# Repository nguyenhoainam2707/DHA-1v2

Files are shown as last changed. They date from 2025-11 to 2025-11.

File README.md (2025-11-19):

# 🌟 DHA-1 Industrial IoT Data Acquisition System

<div align="center">






**Professional Industrial IoT Data Acquisition System**  
*Powered by ESP32-S3 with Web-based Configuration Portal*

</div>

---

## 📋 Mục Lục

- [🔍 Giới Thiệu](#-giới-thiệu)
- [✨ Tính Năng Chính](#-tính-năng-chính)
- [🏗️ Cấu Trúc Dự Án](#️-cấu-trúc-dự-án)
- [🛠️ Cài Đặt và Build](#️-cài-đặt-và-build)
- [🌐 Web Configuration Portal](#-web-configuration-portal)
- [📡 API Documentation](#-api-documentation)
- [🔧 Hardware Requirements](#-hardware-requirements)
- [📊 Protocols Supported](#-protocols-supported)
- [🚀 Quick Start](#-quick-start)
- [📖 Hướng Dẫn Sử Dụng](#-hướng-dẫn-sử-dụng)
- [🤝 Contributing](#-contributing)

---

## 🔍 Giới Thiệu

**DHA-1** là hệ thống thu thập dữ liệu công nghiệp IoT chuyên nghiệp được xây dựng trên nền tảng **ESP32-S3**. Hệ thống cung cấp giao diện web hiện đại để cấu hình và giám sát đến **10 sensor** với nhiều giao thức khác nhau, bao gồm **ADC 4-20mA** và **RS485 Modbus**, đồng thời cung cấp cho người dùng các cảnh báo, để điều khiển các relay hoặc đọc trạng thái của cảm biến thông qua các input đầu vào. 

### 🎯 Mục Tiêu

- **Đơn giản hóa** việc cấu hình hệ thống công nghiệp
- **Chuẩn hóa** giao diện web cho các thiết bị IoT
- **Tối ưu hóa** hiệu suất và độ tin cậy
- **Mở rộng** khả năng tích hợp với các hệ thống SCADA/MES

---

## ✨ Tính Năng Chính

### 🌐 **Web Configuration Portal**
- ✅ Giao diện web responsive hiện đại
- ✅ Dashboard real-time với cập nhật tự động 
- ✅ Cấu hình sensor với Point Table Calibration
- ✅ Cấu hình truyền file FTP theo thông tư 10 và 17 BTNMT
- ✅ Authentication với mật khẩu và password
- ✅ Export/Import cấu hình dạng JSON

### 📊 **Multi-Protocol Sensor Support**
- ✅ **ADC 4-20mA**: 4 cổng dọc tín hiệu analog chuẩn công nghiệp
- ✅ **RS485 Modbus RTU**: 2 channels, mỗi channel tối đa 10 slaves
- ✅ **Digital Input**: 4 channels
- ✅ **Digital Output**: 4 channels

### 🔧 **Advanced Features**
- ✅ **Real-time Clock (RTC)**: DS3231 với battery backup
- ✅ **LCD Display**: 16x2 I2C với backlight control
- ✅ **SD Card Logging**: Automatic data logging
- ✅ **MQTT Integration**: Publish/Subscribe capabilities
- ✅ **FTP Server**: Remote file management

### 📱 **User Experience**
- ✅ **Tabbed Interface**: Organized configuration sections
- ✅ **Live Data Updates**: 2-second refresh rate
- ✅ **Mobile Responsive**: Works on phones and tablets
- ✅ **Error Handling**: Comprehensive error action
- ✅ **Auto-restart**: Configuration changes trigger restart

---

## 🏗️ Cấu Trúc Dự Án

```
DHA-1/
├── 📁 src/
│   ├── 📄 main.cpp                    # Entry point
│   ├── 📁 apps/                       # Application modules
│   │   ├── 📄 App.h                   # Base application class
│   │   ├── 📄 atApp_AP.h              # Access Point & Web Server
│   │   ├── 📄 atApp_Sensor.h          # Sensor management
│   │   ├── 📄 atApp_MQTT_PUB.h        # MQTT Publisher
│   │   ├── 📄 atApp_RTC_v2.h          # Real-time Clock
│   │   ├── 📄 atApp_LCD.h             # LCD Display
│   │   ├── 📄 webApp.h                # Web interface (auto-generated)
│   │   └── 📄 ...                     # Other application modules
│   ├── 📁 obj/                        # Data objects
│   │   ├── 📄 Object.h                # Base object class
│   │   ├── 📄 atObj_Data.h            # Runtime data structure
│   │   └── 📄 atObj_Param.h           # Configuration parameters
│   └── 📁 services/                   # Hardware abstraction
│       ├── 📄 Service.h               # Base service class
│       ├── 📄 atService_ADS1115.h     # ADC service
│       ├── 📄 atService_Modbus.h      # Modbus RTU
│       ├── 📄 atService_DS3231.h      # RTC service
│       └── 📄 ...                     # Other hardware services
├── 📁 data/                           # Web assets
│   ├── 📄 webApp.html                 # Main web interface
│   └── 📄 sensor.html                 # Sensor calibration table
├── 📁 lib/                            # External libraries (ZIP format)
│   ├── 📦 ArduinoJson.zip
│   ├── 📦 RTClib.zip
│   ├── 📦 ModbusMaster.zip
│   └── 📦 ...
├── 📄 platformio.ini                  # PlatformIO configuration
├── 📄 embed_html.py                   # Build script (HTML embedding)
└── 📄 README.md                       # This file
```

---

## 🛠️ Cài Đặt và Build

### 📋 Prerequisites

- **PlatformIO IDE** hoặc **PlatformIO Core**
- **ESP32-S3** DHA-1v1
- **USB-B cable** cho lập trình

### 🚀 Build Instructions

1. **Clone repository:**
```bash
git clone https://github.com/MINHDUONGJSC/DHA-1.git
cd DHA-1
```

2. **Install dependencies:**
```bash
pio lib install
```

3. **Build firmware:**
```bash
pio run
```

4. **Upload to ESP32-S3:**
```bash
pio run --target upload
```

5. **Monitor serial output:**
```bash
pio device monitor
```

### ⚙️ Configuration Files

| File | Purpose | Format |
|---|---|---|
| `platformio.ini` | Build configuration | INI |
| `embed_html.py` | HTML embedding script | Python |

---

## 🌐 Web Configuration Portal

### 🔐 Access Information

- **SSID**: `DHA-1`
- **Password**: `12345678`
- **IP Address**: `192.168.4.1`
- **Login**: `admin` / `admin123`

### 📱 Interface Features

#### 🏠 **Dashboard Tab**
- **Real-time sensor readings** (update every 2 seconds)
- **System status indicators**
- **Alarm and warning displays**
- **Uptime and memory usage**

#### ⚙️ **Configuration Tabs**

| Tab | Description | Features |
|-----|---|---|
| **General** | System settings | Device name, time zone, network |
| **Sensors** | Sensor configuration | Protocol, calibration, limits |
| **Digital I/O** | I/O configuration | Input/output mapping, control logic |
| **RS485** | Modbus settings | 2 channels, 10 slaves per channel |
| **MQTT** | MQTT integration | Broker settings, topics |
| **RTC** | Time settings | Auto-sync, timezone |
| **LCD** | Display settings | Backlight, refresh rate |

#### 🔧 **Advanced Features**

- **Point Table Calibration**: 10-point linearization
- **Error Thresholds**: Configurable alarm levels
- **Data Export**: Download configuration as JSON
- **Firmware Update**: OTA capability
- **Log Viewer**: Real-time log display

---

## 📡 API Documentation

### 🔑 Authentication

All API calls require JWT authentication header:
```http
Authorization: Bearer <token>
```

### 🌐 Endpoints

#### **Authentication**
```http
POST /api/login
Content-Type: application/json

{
  "username": "admin",
  "password": "admin123"
}
```

#### **Configuration**
```http
GET /api/config          # Get full configuration
POST /api/save           # Save configuration
GET /api/dashboard       # Get real-time data
GET /api/rtc            # Get RTC information
```

#### **Response Format**
```json
{
  "success": true,
  "data": {
    "sensors": [
      {
        "id": 0,
        "name": "Temperature",
        "raw": 2048.5,
        "calib": 25.3,
        "status": 0,
        "unit": "°C"
      }
    ],
    "system": {
      "uptime": 3600,
      "free_heap": 245760,
      "rtc_temp": 24.5
    }
  }
}
```

---

## 🔧 Hardware Requirements

### 💾 **ESP32-S3 Specifications**

| Component | Requirement | Notes |
|---|---|---|
| **MCU** | ESP32-S3 | Dual-core, 240MHz |
| **Flash** | 16MB | For firmware + web assets |
| **PSRAM** | 8MB | For buffering and processing |
| **WiFi** | 802.11 b/g/n | Access Point mode |

### 🔌 **External Components**

| Component | Interface | Purpose |
|---|---|---|
| **ADS1115** | I2C | 16-bit ADC for 4-20mA |
| **DS3231** | I2C | Real-time clock |
| **LCD 16x2** | I2C | Local display |
| **SD Card** | SPI | Data logging |
| **RS485 Transceiver x2** | UART | 2-channel Modbus communication |
| **PCF8574** | I2C | I/O expansion |
| **74HC595** | SPI | Output expansion |

---

## 📊 Protocols Supported

### 🔧 **ADC 4-20mA**
- **Resolution**: 16-bit (ADS1115)
- **Range**: 4-20mA industrial standard
- **Accuracy**: ±0.1% FSR
- **Calibration**: Point table or polynomial

### 📡 **RS485 Modbus RTU**
- **Channels**: 2 independent channels
- **Slaves per Channel**: Up to 10 devices
- **Total Slaves**: Maximum 20 devices
- **Baud Rate**: 9600, 19200, 38400, 115200
- **Data Bits**: 8
- **Parity**: None, Even, Odd
- **Stop Bits**: 1, 2
- **Functions**: 03 (Read Holding), 04 (Read Input)

### 🌐 **MQTT**
- **Version**: 3.1.1
- **QoS**: 0, 1, 2
- **Topics**: Configurable publish/subscribe
- **Payload**: JSON format
- **SSL/TLS**: Supported

---

## 🚀 Quick Start

### 1️⃣ **Hardware Setup**
```
1. Connect ESP32-S3 to power
2. Wire I2C devices (SDA=21, SCL=22)
3. Connect RS485 transceiver
4. Insert SD card
5. Power on system
```

### 2️⃣ **Network Connection**
```
1. Connect to WiFi "DHA-1"
2. Password: "12345678"
3. Open browser: http://192.168.4.1
4. Login: admin / admin123
```

### 3️⃣ **Sensor Configuration**
```
1. Go to "Sensors" tab
2. Enable desired sensors
3. Select protocol (ADC/RS485)
4. Configure calibration
5. Set alarm thresholds
6. Save configuration
```

### 4️⃣ **Monitoring**
```
1. Switch to "Dashboard" tab
2. View real-time data
3. Monitor system status
4. Check alarm conditions
```

---

## 📖 Hướng Dẫn Sử Dụng

### 🔧 **Cấu Hình Sensor**

#### **ADC 4-20mA Setup:**
1. Chọn **Protocol**: ADC
2. Cấu hình **Calibration**:
   - Linear: `y = A + Bx`
   - Point Table: Nhập 10 điểm chuẩn
3. Thiết lập **Error Thresholds**
4. Cấu hình **Output Limits**

#### **RS485 Modbus Setup:**
1. Chọn **Protocol**: RS485
2. Chọn **Channel** (1 hoặc 2)
3. Chọn **Slave Device** (1-10 per channel)
4. Cấu hình **Register Address**
5. Thiết lập **Data Type** (INT16, FLOAT, etc.)
6. Áp dụng **Calibration Function**

### 📊 **Dashboard Usage**

- **Sensor Cards**: Hiển thị real-time data
- **Status Colors**:
  - 🟢 **Green**: Normal operation
  - 🟡 **Orange**: Calibration mode
  - 🔴 **Red**: Error condition
- **Auto-refresh**: Cập nhật mỗi 2 giây

### 💾 **Data Management**

- **Save Config**: Lưu cấu hình vào SD card
- **Export**: Download file JSON
- **Backup**: Tự động backup định kỳ
- **Restore**: Import từ file JSON

---

## 🤝 Contributing

### 📋 **Development Guidelines**

1. **Fork** repository
2. **Create** feature branch
3. **Follow** coding standards
4. **Test** thoroughly
5. **Submit** pull request

### 🐛 **Bug Reports**

Sử dụng GitHub Issues với template:
- **Environment**: Hardware, firmware version
- **Steps**: Cách tái hiện lỗi
- **Expected**: Kết quả mong đợi
- **Actual**: Kết quả thực tế

### 💡 **Feature Requests**

- Mô tả chi tiết tính năng
- Giải thích use case
- Đề xuất implementation

---

## 📞 Contact & Support

<div align="center">

**🏢 MASSOFT**  
*Industrial IoT & Automation Solutions*

📧 **Email**: support@massoft.vn  
🌐 **Website**: https://massoft.vn  
📱 **Phone**: +84 XXX XXX XXX

---

**© 2025 MASSOFT. All rights reserved.**

</div>

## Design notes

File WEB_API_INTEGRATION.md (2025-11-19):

# Web API Integration Guide

## Đã hoàn thành trong atApp_AP.h

### 1. Access Point Configuration
- **SSID**: `DHA-1_Config`
- **Password**: `12345678`
- **IP Address**: `192.168.4.1`
- **Max Connections**: 4 clients

### 2. API Endpoints

#### Authentication
- **POST** `/api/login`
  - Body: `{"username":"admin", "password":"admin123"}`
  - Response: `{"success":true, "token":"xxxxx"}`

- **POST** `/api/logout`
  - Response: `{"success":true, "message":"Logged out"}`

#### Configuration
- **GET** `/api/config` (requires auth)
  - Returns full configuration from atObj_Param

- **POST** `/api/save` (requires auth)
  - Body: Full configuration JSON
  - Saves to SD card and restarts ESP32

#### Dashboard
- **GET** `/api/dashboard` (requires auth)
  - Returns real-time sensor data from atObj_Data

### 3. Cần cập nhật trong webApp.html

#### Function: handleLogin()
```javascript
function handleLogin(event) {
    event.preventDefault();
    
    const username = document.getElementById('loginUsername').value;
    const password = document.getElementById('loginPassword').value;
    
    fetch('http://192.168.4.1/api/login', {
        method: 'POST',
        headers: { 'Content-Type': 'application/json' },
        body: JSON.stringify({ username, password })
    })
    .then(response => response.json())
    .then(data => {
        if (data.success) {
            localStorage.setItem('authToken', data.token);
            hideLogin();
            loadConfiguration(); // Load config after login
        } else {
            document.getElementById('loginError').style.display = 'block';
        }
    })
    .catch(error => console.error('Login error:', error));
}
```

#### Function: loadConfiguration()
```javascript
function loadConfiguration() {
    fetch('http://192.168.4.1/api/config', {
        method: 'GET',
        headers: { 'Authorization': 'Bearer ' + localStorage.getItem('authToken') }
    })
    .then(response => response.json())
    .then(data => {
        // Populate form fields with data
        if (data.device_info) {
            document.getElementById('deviceName').value = data.device_info.device_name;
            document.getElementById('deviceId').value = data.device_info.device_id;
            // ... populate other fields
        }
        
        if (data.sensors) {
            data.sensors.forEach((sensor, index) => {
                // Populate sensor configuration
            });
        }
        
        // ... populate MQTT, RTC, etc.
    })
    .catch(error => console.error('Load config error:', error));
}
```

#### Function: saveConfig()
```javascript
function saveConfig() {
    // Collect all form data
    const config = {
        device_info: {
            device_name: document.getElementById('deviceName').value,
            device_id: document.getElementById('deviceId').value,
            // ... collect other fields
        },
        lcd_config: {
            enable: document.getElementById('lcdEnable').checked,
            backlight_enable: document.getElementById('lcdBacklight').checked,
            refresh_rate: parseInt(document.getElementById('lcdRefreshRate').value)
        },
        sensors: [],
        mqtt: {},
        rtc: {}
        // ... collect all configurations
    };
    
    fetch('http://192.168.4.1/api/save', {
        method: 'POST',
        headers: { 
            'Content-Type': 'application/json',
            'Authorization': 'Bearer ' + localStorage.getItem('authToken')
        },
        body: JSON.stringify(config)
    })
    .then(response => response.json())
    .then(data => {
        if (data.success) {
            showMessage('Configuration saved! Device restarting...', 'success');
        } else {
            showMessage('Failed to save: ' + data.message, 'error');
        }
    })
    .catch(error => {
        console.error('Save error:', error);
        showMessage('Network error: ' + error, 'error');
    });
}
```

#### Function: updateDashboard()
```javascript
function updateDashboard() {
    fetch('http://192.168.4.1/api/dashboard', {
        method: 'GET',
        headers: { 'Authorization': 'Bearer ' + localStorage.getItem('authToken') }
    })
    .then(response => response.json())
    .then(data => {
        if (data.sensors) {
            data.sensors.forEach(sensor => {
                // Update dashboard display
                document.getElementById('sensor' + sensor.id + 'Raw').value = sensor.raw.toFixed(2);
                document.getElementById('sensor' + sensor.id + 'Calib').value = sensor.calib.toFixed(2);
                document.getElementById('sensor' + sensor.id + 'Status').textContent = getStatusText(sensor.status);
            });
        }
        
        // Update system info
        document.getElementById('uptime').textContent = formatUptime(data.uptime);
        document.getElementById('freeHeap').textContent = formatBytes(data.free_heap);
        document.getElementById('clients').textContent = data.clients;
    })
    .catch(error => console.error('Dashboard update error:', error));
}

// Auto-refresh dashboard every 2 seconds
setInterval(updateDashboard, 2000);
```

### 4. Security Notes

⚠️ **Important**: Current implementation uses simple authentication
- Username: `admin`
- Password: `admin123`
- Session timeout: 1 hour

**Khuyến nghị cho production:**
1. Thay đổi mật khẩu mặc định
2. Sử dụng HTTPS (ESP32 hỗ trợ)
3. Implement proper JWT tokens
4. Hash passwords với bcrypt
5. Add CSRF protection

### 5. Memory Management

Code đã được tối ưu hóa để tránh tràn RAM:
- Sử dụng `JsonDocument` với auto memory management (ArduinoJson v7)
- Gửi JSON theo chunks nhỏ thay vì full config
- Clear JSON document sau khi sử dụng: `doc.clear()`
- Delay 500ms trước khi restart để đảm bảo response được gửi

### 6. Testing Checklist

- [ ] Kết nối WiFi AP "DHA-1_Config"
- [ ] Truy cập http://192.168.4.1
- [ ] Login với admin/admin123
- [ ] Load configuration từ SD card
- [ ] Chỉnh sửa các thông số
- [ ] Save configuration
- [ ] Kiểm tra file Config.json trên SD card
- [ ] Verify ESP32 restart sau khi save
- [ ] Dashboard hiển thị real-time data

### 7. Troubleshooting

**Lỗi "Unauthorized":**
- Kiểm tra localStorage có authToken không
- Session có thể đã timeout (1 giờ)
- Login lại

**Lỗi "SD card not available":**
- Kiểm tra SD card được khởi tạo chưa
- Gọi `atService_SD.begin()` trong main code

**RAM overflow:**
- Giảm số sensors hiển thị trên dashboard
- Tăng delay giữa các request
- Monitor free heap: `ESP.getFreeHeap()`

**Web không load:**
- Kiểm tra đã include file `webApp.h`
- File HTML quá lớn → nén hoặc chia nhỏ
- Tăng stack size của task: `xTaskCreate(..., 8192, ...)`

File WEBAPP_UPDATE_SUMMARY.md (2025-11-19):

# WebApp.html JavaScript Integration - Hoàn Tất

## Tóm Tắt Thay Đổi

Đã cập nhật hoàn tất các hàm JavaScript trong `webApp.html` để kết nối với ESP32 REST API.

---

## 1. Hàm loadConfiguration()

**Mục đích:** Tải cấu hình từ ESP32 và điền vào các trường form

**Endpoint:** `GET /api/config`

**Chức năng:**
- Lấy auth token từ localStorage
- Gửi GET request với Bearer token
- Parse JSON response và điền vào tất cả các trường:
  - Device Info (name, id, firmware version)
  - LCD Config (enable, backlight, refresh rate)
  - AI Config (refresh rate, 4 channels)
  - DO Config (refresh rate, 4 channels)
  - DI Config (refresh rate, 4 channels)
  - Sensor Config (10 sensors với đầy đủ thông số)
  - MQTT Config (host, port, credentials, topics)
  - RTC Config (enable flag)

**Error Handling:**
- 401 Unauthorized → logout và hiển thị login modal
- Network errors → hiển thị thông báo lỗi

**Được gọi:** Sau khi login thành công

---

## 2. Hàm saveConfig()

**Mục đích:** Lưu cấu hình xuống SD card và restart ESP32

**Endpoint:** `POST /api/save`

**Chức năng:**
- Thu thập tất cả dữ liệu từ form fields
- Build JSON object với cấu trúc hoàn chỉnh
- Gửi POST request với Bearer token
- Hiển thị thông báo "Device restarting..."
- Clear auth token sau 3 giây (do ESP32 restart)
- Redirect về login page

**Quy trình:**
1. Confirm dialog → OK?
2. Collect form data
3. POST to /api/save
4. ESP32 updates atObj_Param
5. ESP32 calls saveConfigToJSON()
6. ESP32 delays 500ms
7. ESP32 calls ESP.restart()
8. WebApp shows countdown and logout

**Error Handling:**
- 401 Unauthorized → logout
- Network/Server errors → hiển thị lỗi

---

## 3. Hàm updateDashboard()

**Mục đích:** Cập nhật real-time data lên dashboard

**Endpoint:** `GET /api/dashboard`

**Chức năng:**
- Lấy auth token (skip nếu chưa login)
- Gửi GET request với Bearer token
- Parse JSON và cập nhật readonly fields:
  - sensor_raw_value_list[0-9] → sensor-raw-1 to sensor-raw-10
  - sensor_calib_value_list[0-9] → sensor-calib-1 to sensor-calib-10
  - sensor_status_list[0-9] → sensor-status-1 to sensor-status-10
    * 0 = Normal (green)
    * 1 = Calibration (orange)
    * 2 = Error (red)
  - ai_raw_value_list[0-3] (optional)
  - di_status_list[0-3] (optional)
  - do_status_list[0-3] (optional)

**Auto-refresh:**
- `setInterval(updateDashboard, 2000)` → cập nhật mỗi 2 giây
- Dừng khi 401 Unauthorized

**Error Handling:**
- 401 → stop refresh (không logout vì có thể đang offline)
- Network errors → log to console only

---

## 4. Helper Functions

### showSuccess(message)
- Hiển thị thông báo thành công màu xanh
- Tự động ẩn sau 5 giây

### showError(message)
- Hiển thị thông báo lỗi màu đỏ
- Tự động ẩn sau 5 giây

---

## Quy Trình Làm Việc Hoàn Chỉnh

### A. First Time Setup
```
1. Connect to WiFi "DHA-1_Config" (password: 12345678)
2. Open browser: http://192.168.4.1
3. Login page appears automatically
4. Enter username/password
5. handleLogin() sends POST /api/login
6. Receive token, save to localStorage
7. loadConfiguration() auto-called
8. Configuration populated in form
9. Dashboard starts auto-refreshing
```

### B. Modify Configuration
```
1. Edit form fields in any tab
2. Click "Save Configuration to SD Card" button
3. Confirm dialog → OK
4. saveConfig() collects all data
5. POST /api/save with complete config
6. ESP32 updates RAM variables
7. ESP32 saves to /CONFIG/Config.json
8. ESP32 delays 500ms (ensure response sent)
9. ESP32 calls ESP.restart()
10. WebApp shows "Device restarting..."
11. After 3s, logout and show login page
12. User reconnects after ~30 seconds
```

### C. Real-time Monitoring
```
1. Switch to "Dashboard" tab
2. updateDashboard() runs every 2 seconds
3. Sensor values update automatically
4. Status colors change based on state
5. No manual refresh needed
```

---

## API Endpoints Đã Tích Hợp

| Endpoint | Method | Function | Auth Required |
|---|---|---|---|
| `/api/login` | POST | handleLogin() | No |
| `/api/logout` | POST | logout() | Yes |
| `/api/config` | GET | loadConfiguration() | Yes |
| `/api/save` | POST | saveConfig() | Yes |
| `/api/dashboard` | GET | updateDashboard() | Yes |
| `/` | GET | (root page) | No |

---

## Authentication Flow

```
Login:
  → POST /api/login {username, password}
  ← {status: "success", token: "xxx"}
  → localStorage.setItem('authToken', token)
  → loadConfiguration()

API Calls:
  → Headers: {'Authorization': 'Bearer ' + token}
  
Logout:
  → POST /api/logout with token
  ← {status: "success"}
  → localStorage.removeItem('authToken')
  → showLogin()

Session Timeout:
  ← 401 Unauthorized
  → Auto logout
  → Show login page
```

---

## Memory Optimization

**ESP32 Side:**
- Use `doc.clear()` after serialization
- Send minimal dashboard JSON (only arrays)
- Chunked responses for large config
- `delay(500)` before restart

**WebApp Side:**
- Conditional dashboard updates (skip if not logged in)
- Error throttling (log only, don't spam UI)
- Clean localStorage on logout

---

## Testing Checklist

- [x] Login with correct credentials
- [x] Login with wrong credentials (should show error)
- [ ] Load configuration after login
- [ ] Verify all form fields populated correctly
- [ ] Edit configuration values
- [ ] Save configuration
- [ ] Verify "Device restarting..." message
- [ ] Verify auto-logout after save
- [ ] Reconnect after restart
- [ ] Verify changes persisted
- [ ] Dashboard auto-refresh working
- [ ] Sensor status colors correct
- [ ] Session timeout after 1 hour
- [ ] Logout button works
- [ ] Multiple tabs sync correctly

---

## Troubleshooting

### Problem: Can't login
**Solution:** Check ESP32 serial monitor for [AP] logs, verify WiFi connection

### Problem: Configuration not loading
**Solution:** Check /CONFIG/Config.json exists on SD card, verify loadConfigFromJSON() works

### Problem: Save doesn't restart device
**Solution:** Check saveConfigToJSON() returns true, verify ESP.restart() is called

### Problem: Dashboard not updating
**Solution:** Check auth token exists, verify /api/dashboard returns data, check console for errors

### Problem: 401 Unauthorized
**Solution:** Token expired (1 hour), logout and login again

---

## Code Locations

- **handleLogin()**: Line ~3392
- **logout()**: Line ~3465
- **loadConfiguration()**: Line ~3210
- **saveConfig()**: Line ~3327
- **updateDashboard()**: Line ~3820
- **showSuccess/showError()**: Line ~3503

---

## Next Steps

1. **Test trên thiết bị thật:**
   - Upload code lên ESP32-S3
   - Connect WiFi AP
   - Test toàn bộ workflow

2. **Bổ sung thêm:**
   - Password change API endpoint
   - Firmware update via web
   - Real-time logs viewer
   - Export config as JSON file
   - Import config from JSON file

3. **Tối ưu hóa:**
   - Compress JSON responses
   - WebSocket cho dashboard (thay vì polling)
   - Progressive Web App (PWA) manifest
   - Offline support

---

**Created:** $(date)
**Status:** ✅ Hoàn tất - Ready for testing
**Version:** 1.0

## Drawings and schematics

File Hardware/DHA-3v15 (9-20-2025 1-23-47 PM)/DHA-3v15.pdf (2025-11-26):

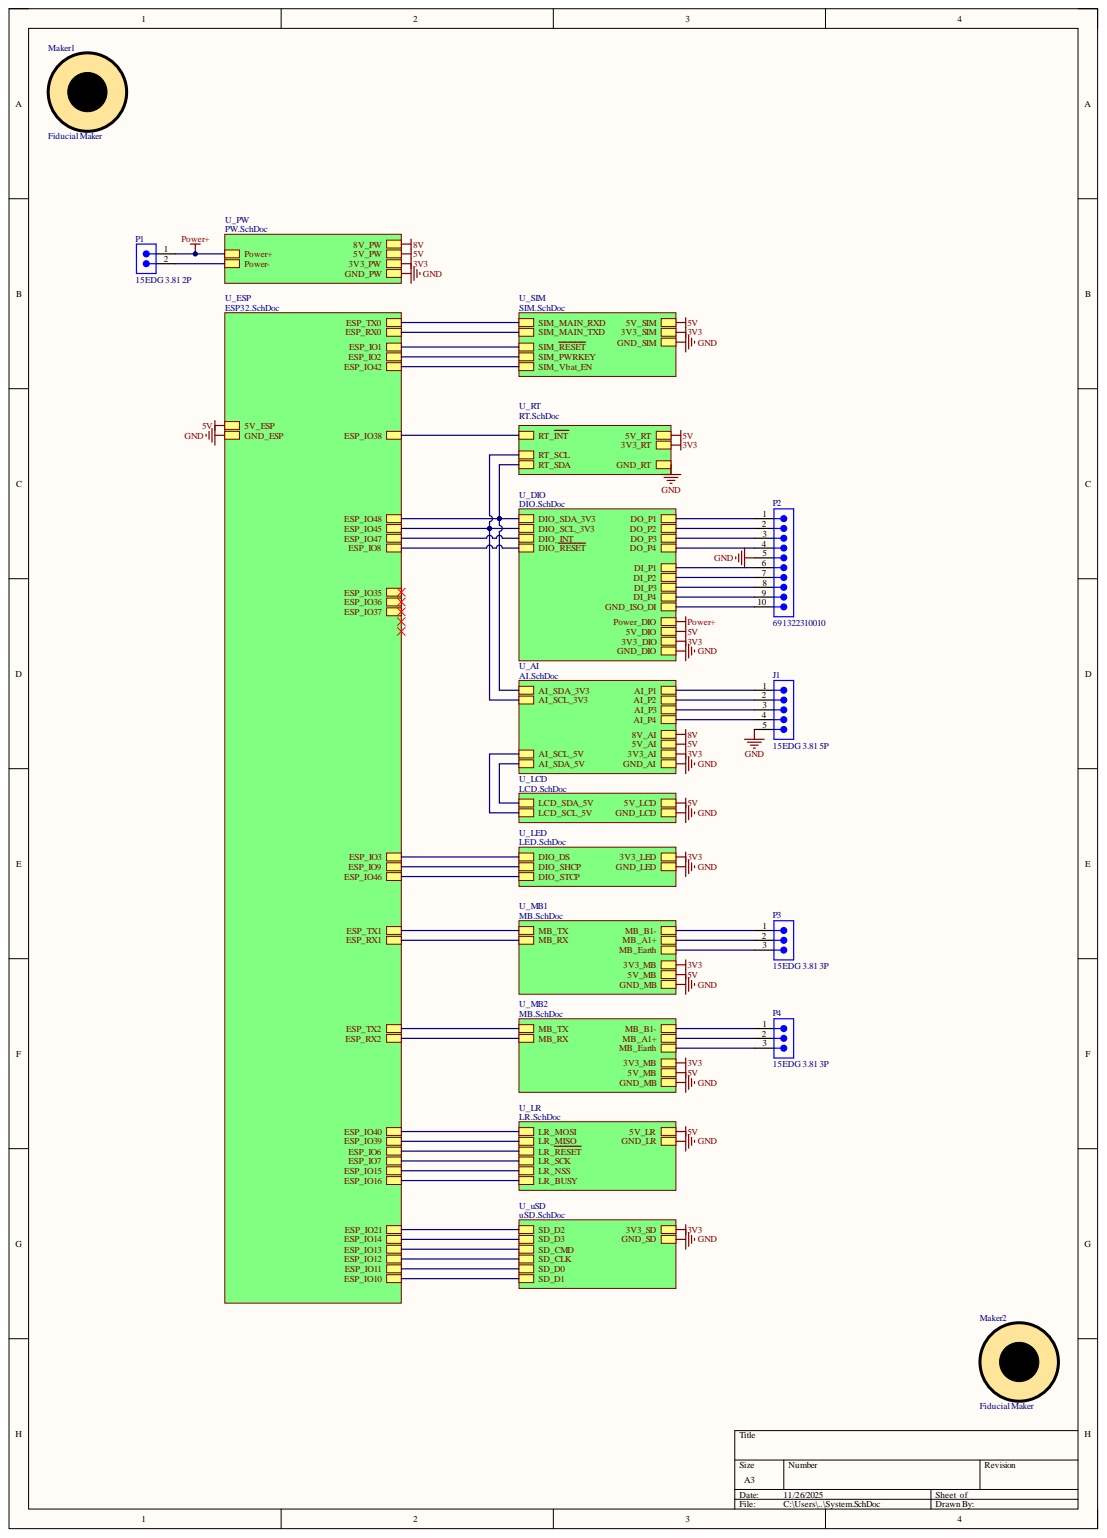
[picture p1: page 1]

Size A3 | Number | Revision

Date: 11/26/2025 | Sheet of
File: C:\Users\..\System.SchDoc | DrawnBy:

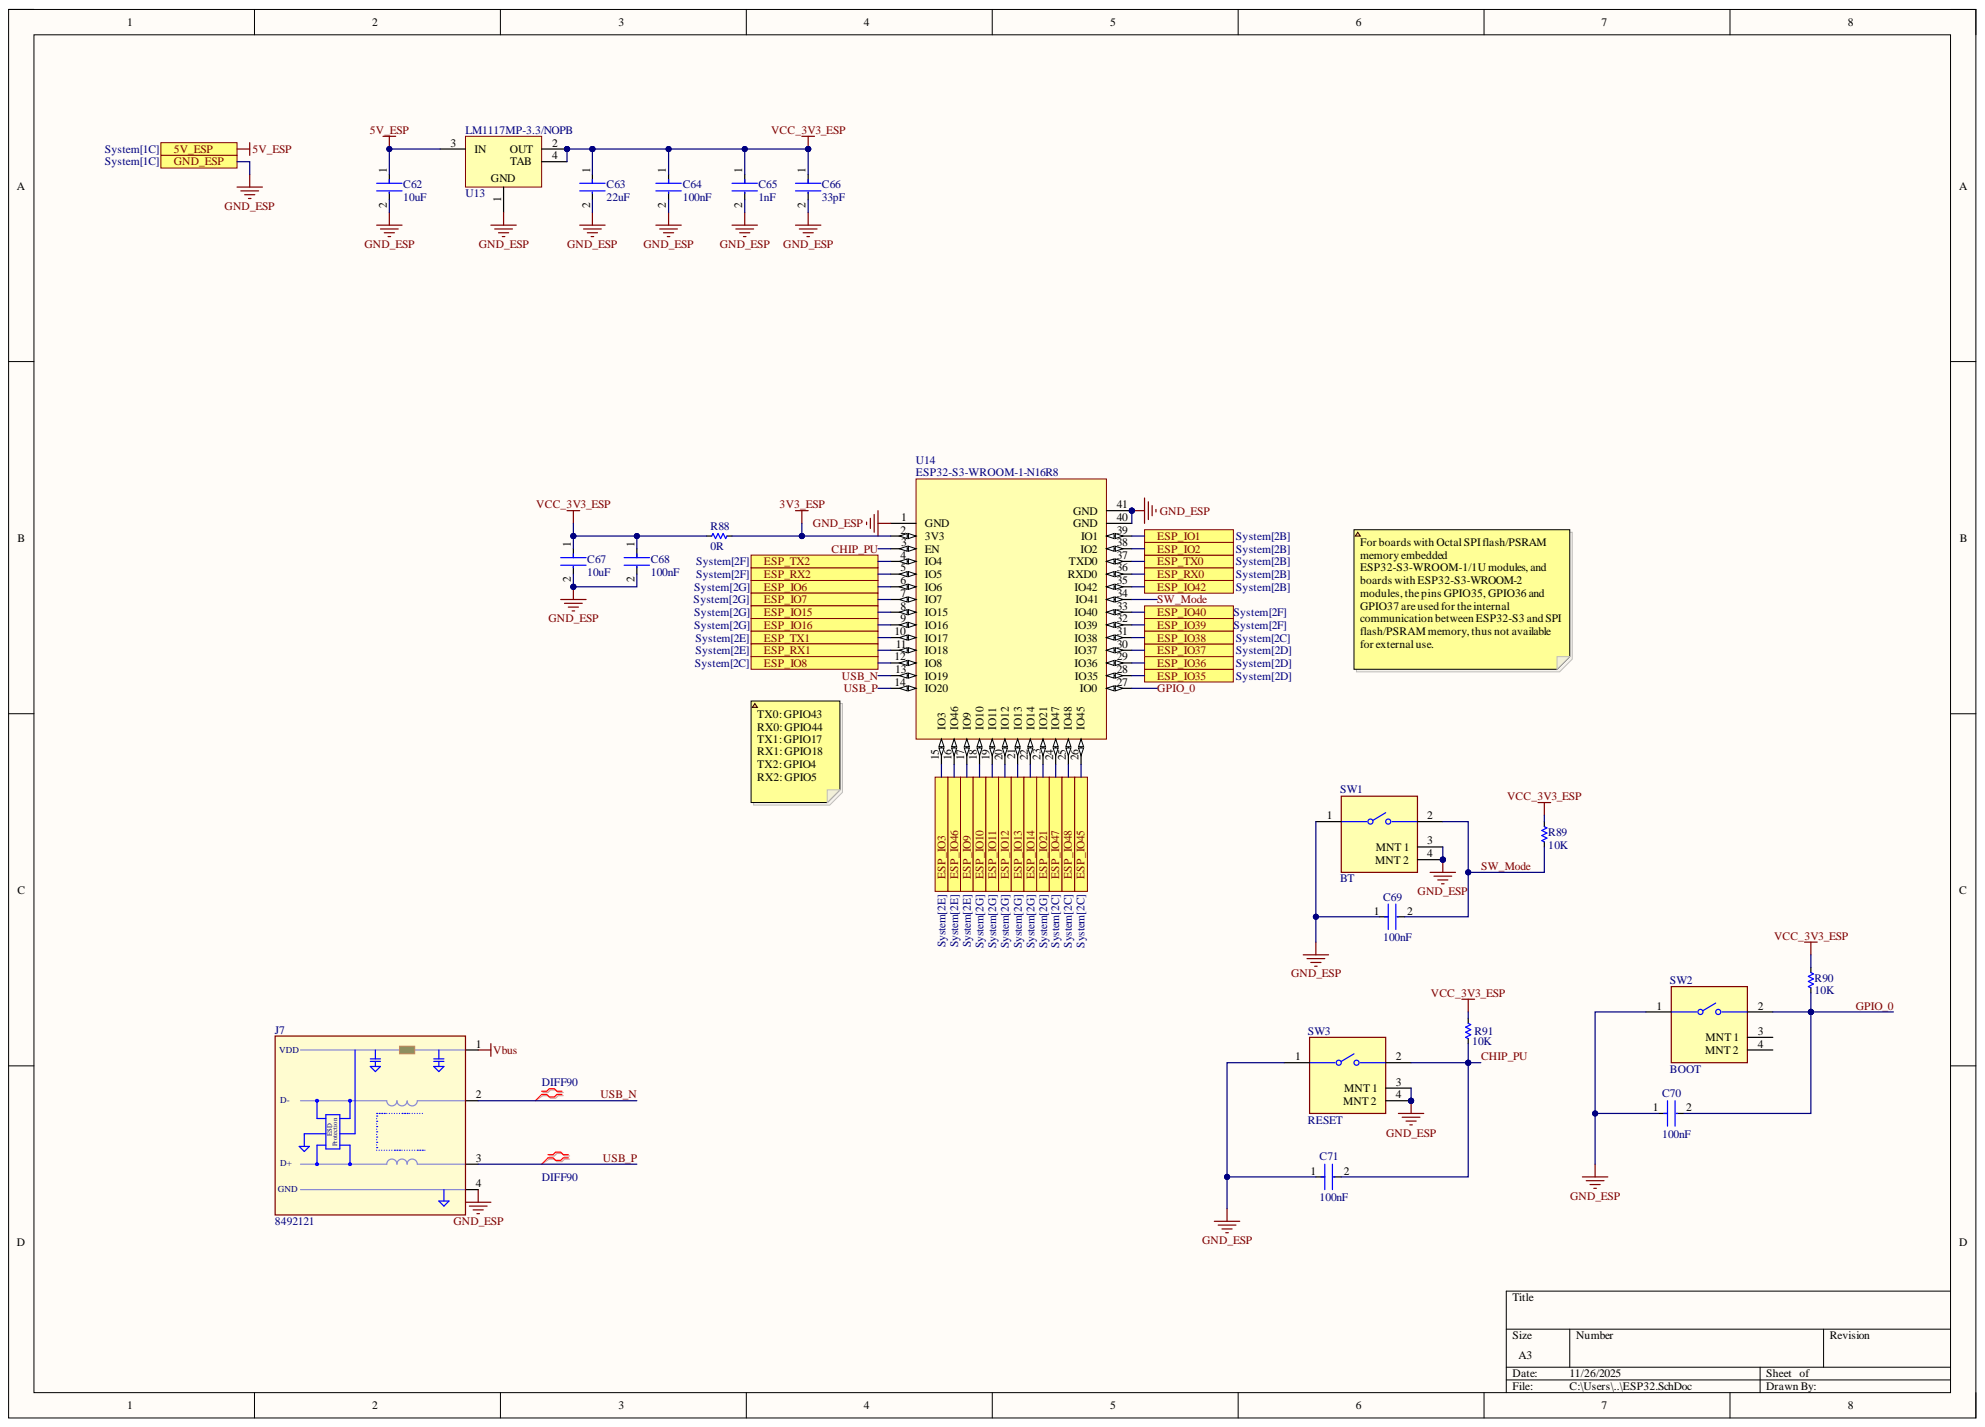
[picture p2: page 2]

For boards with Octal SPIflash/PSRAM
memory embedded
ESP32-S3-WROOM-1/1U modules, and
boards with ESP32-S3-WROOM-2
modules, the pins GPIO35, GPIO36 and
GPIO37 are used for the internal
communication between ESP32-S3 and SPI
flash/PSRAM memory, thus not available
for external use.

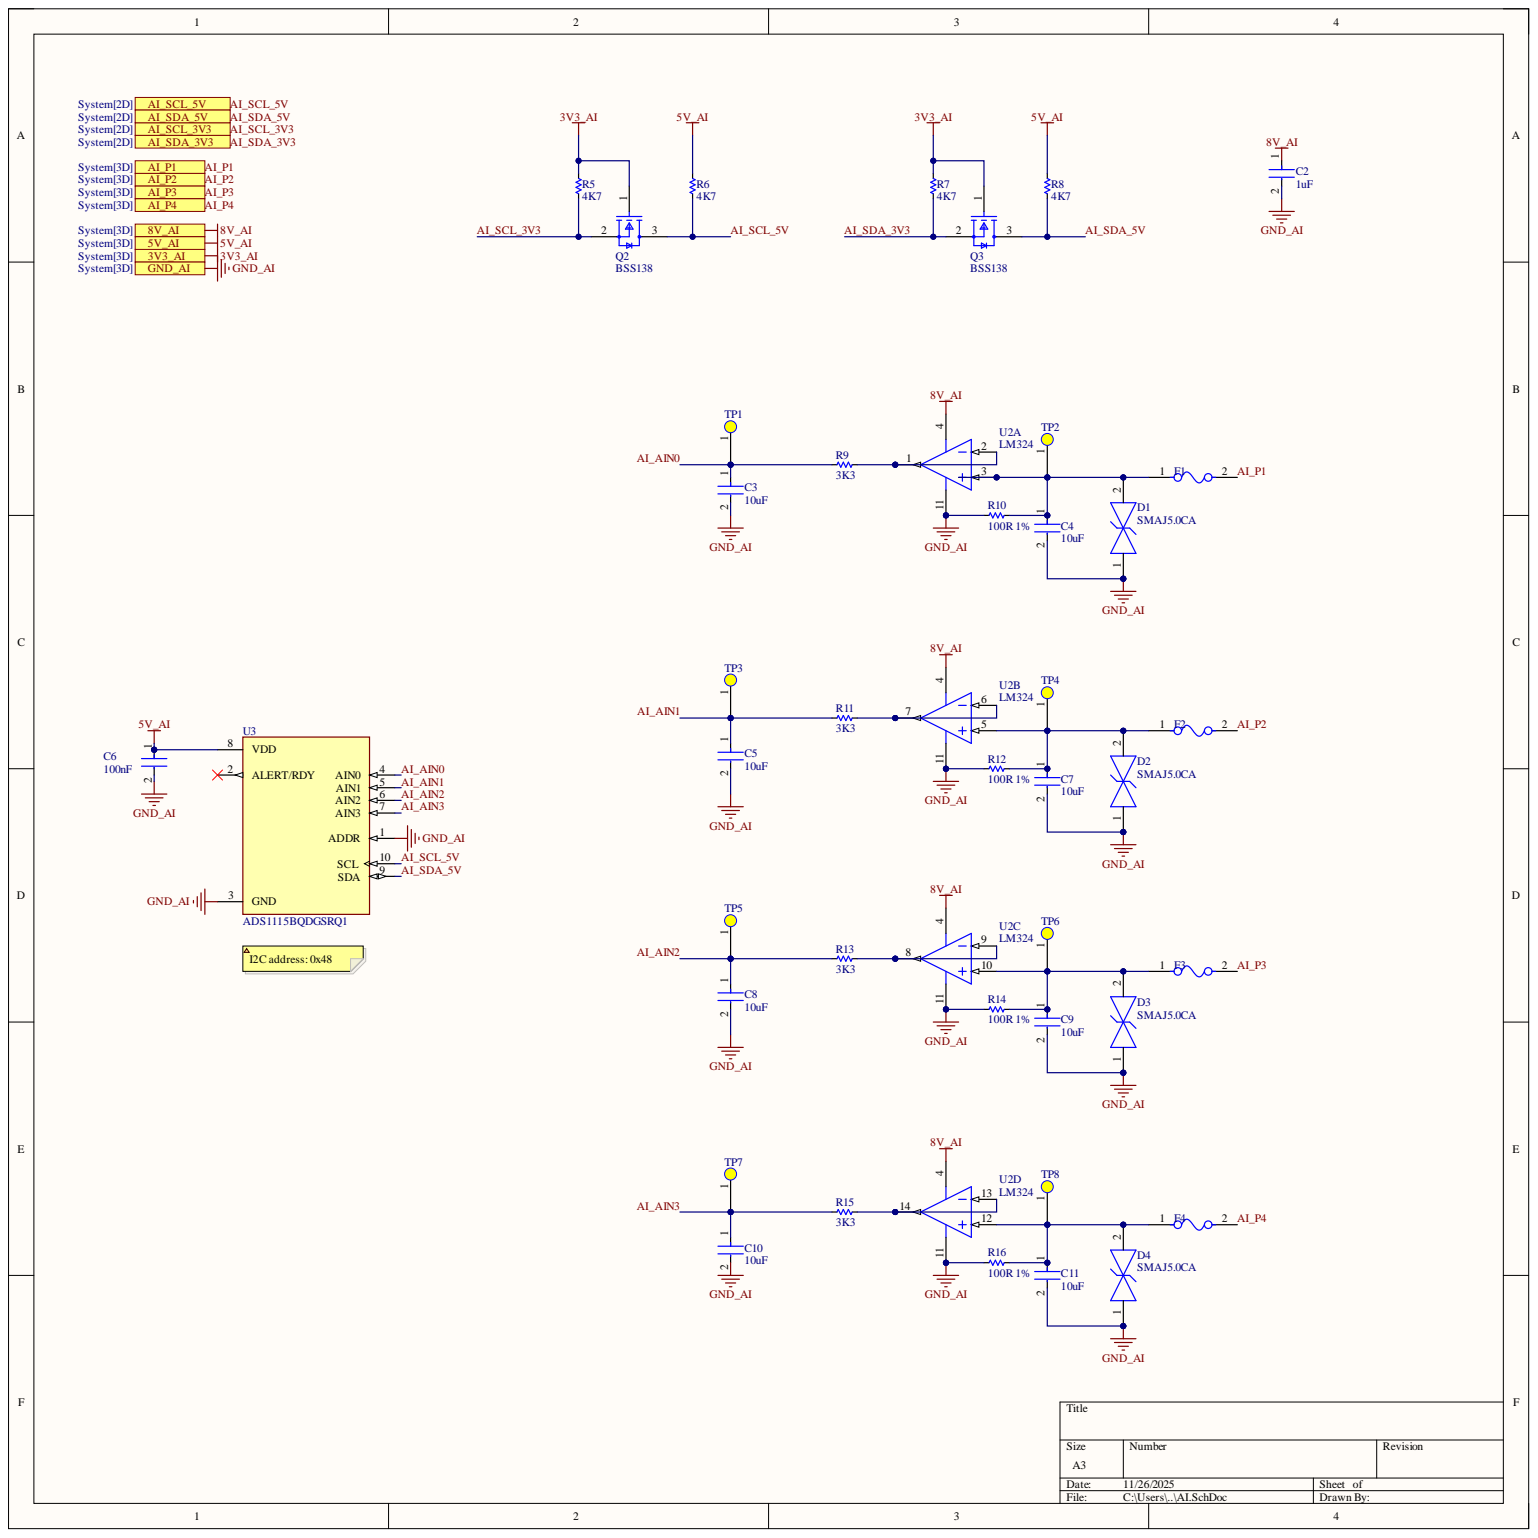
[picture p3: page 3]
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

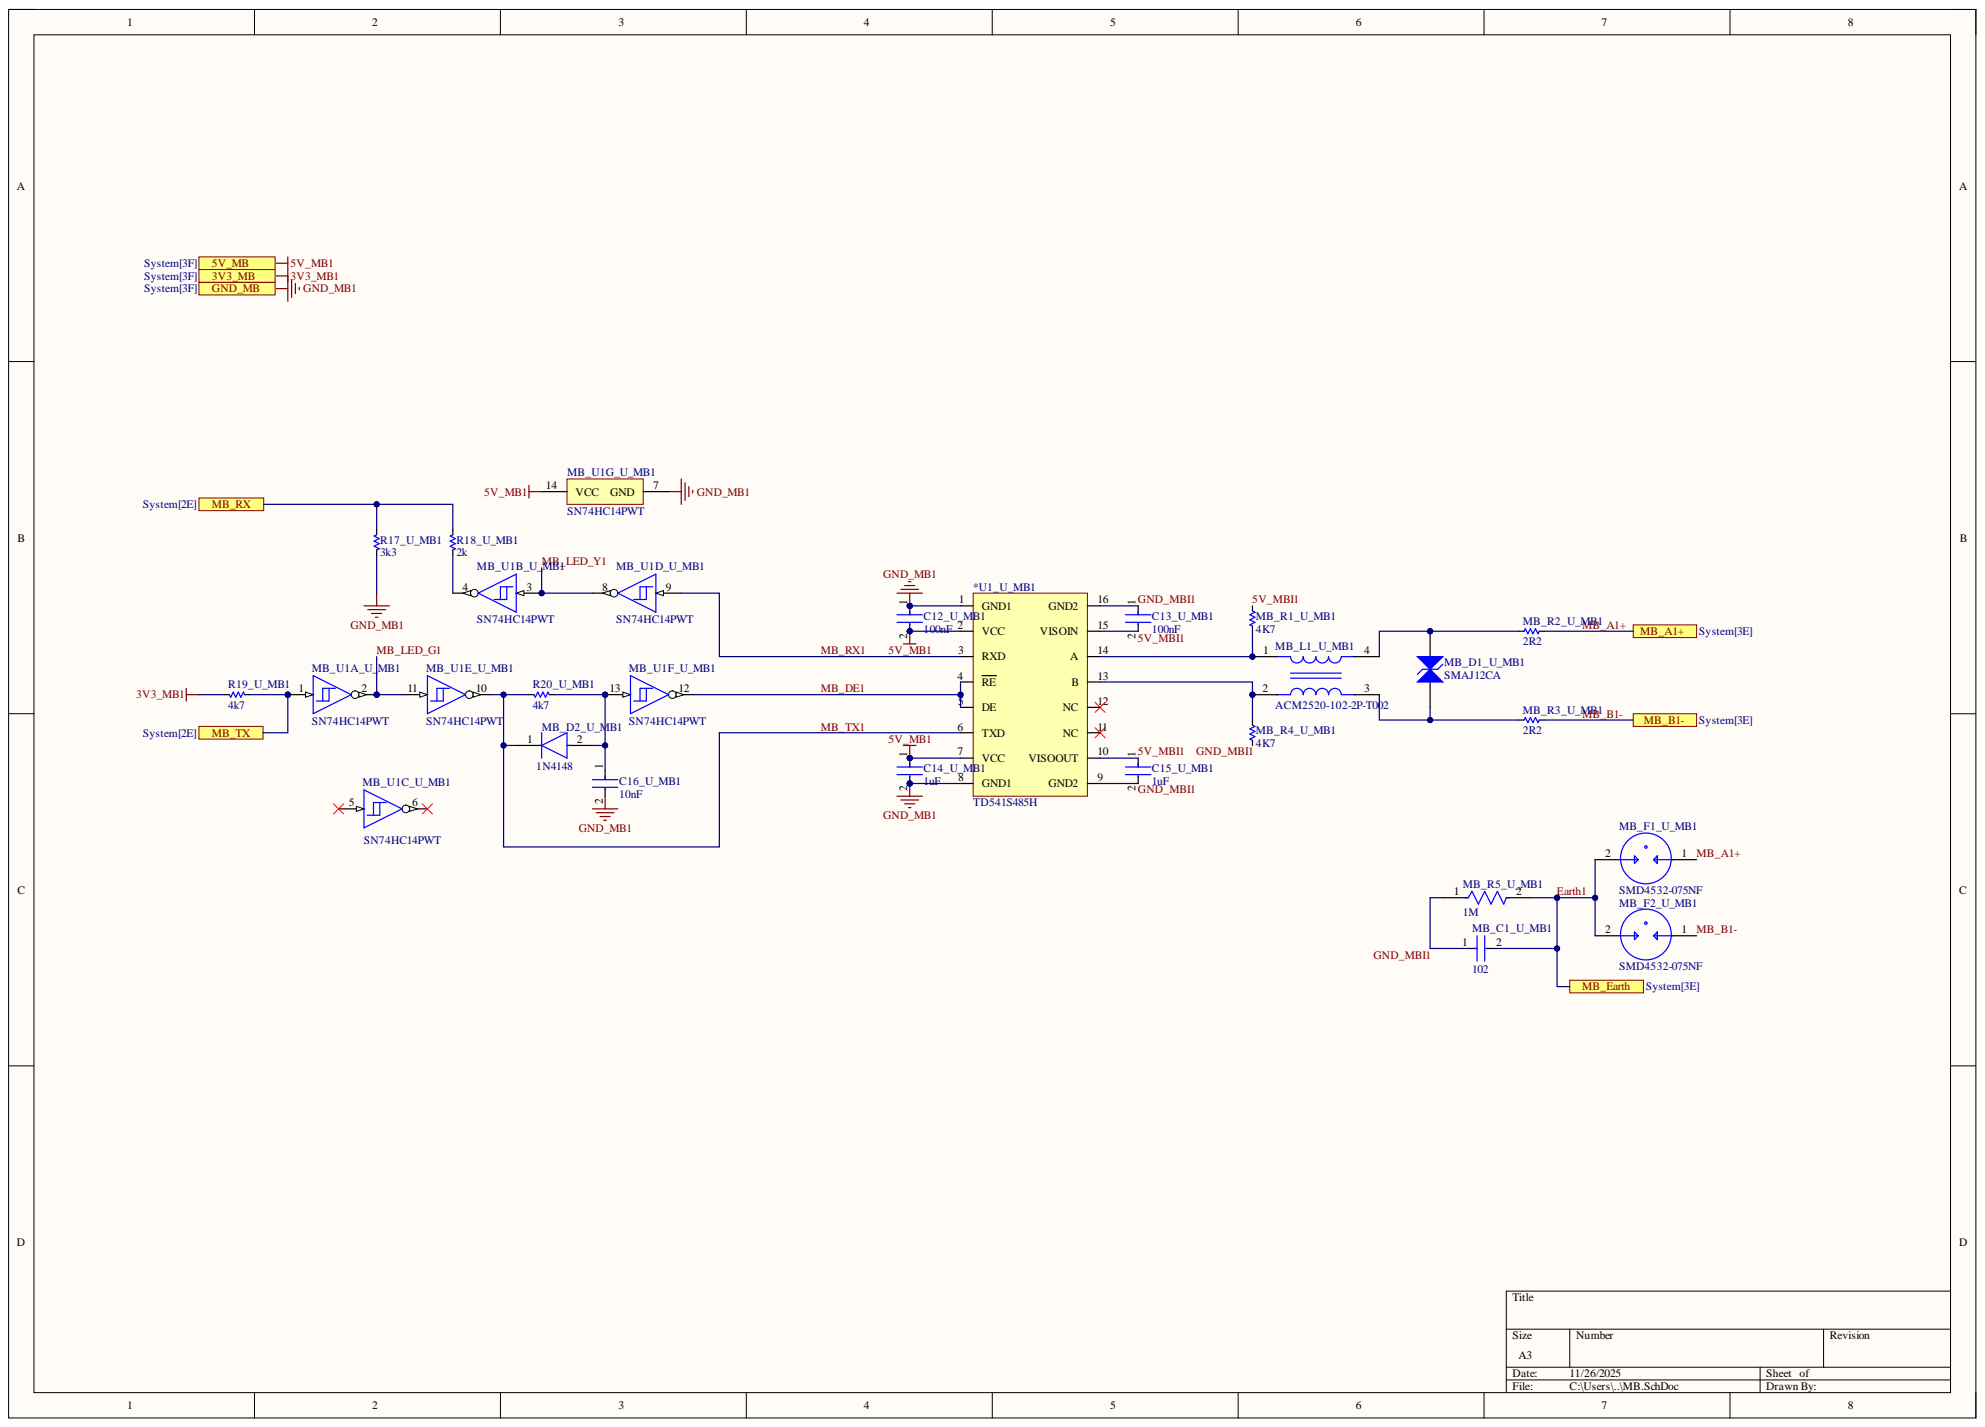
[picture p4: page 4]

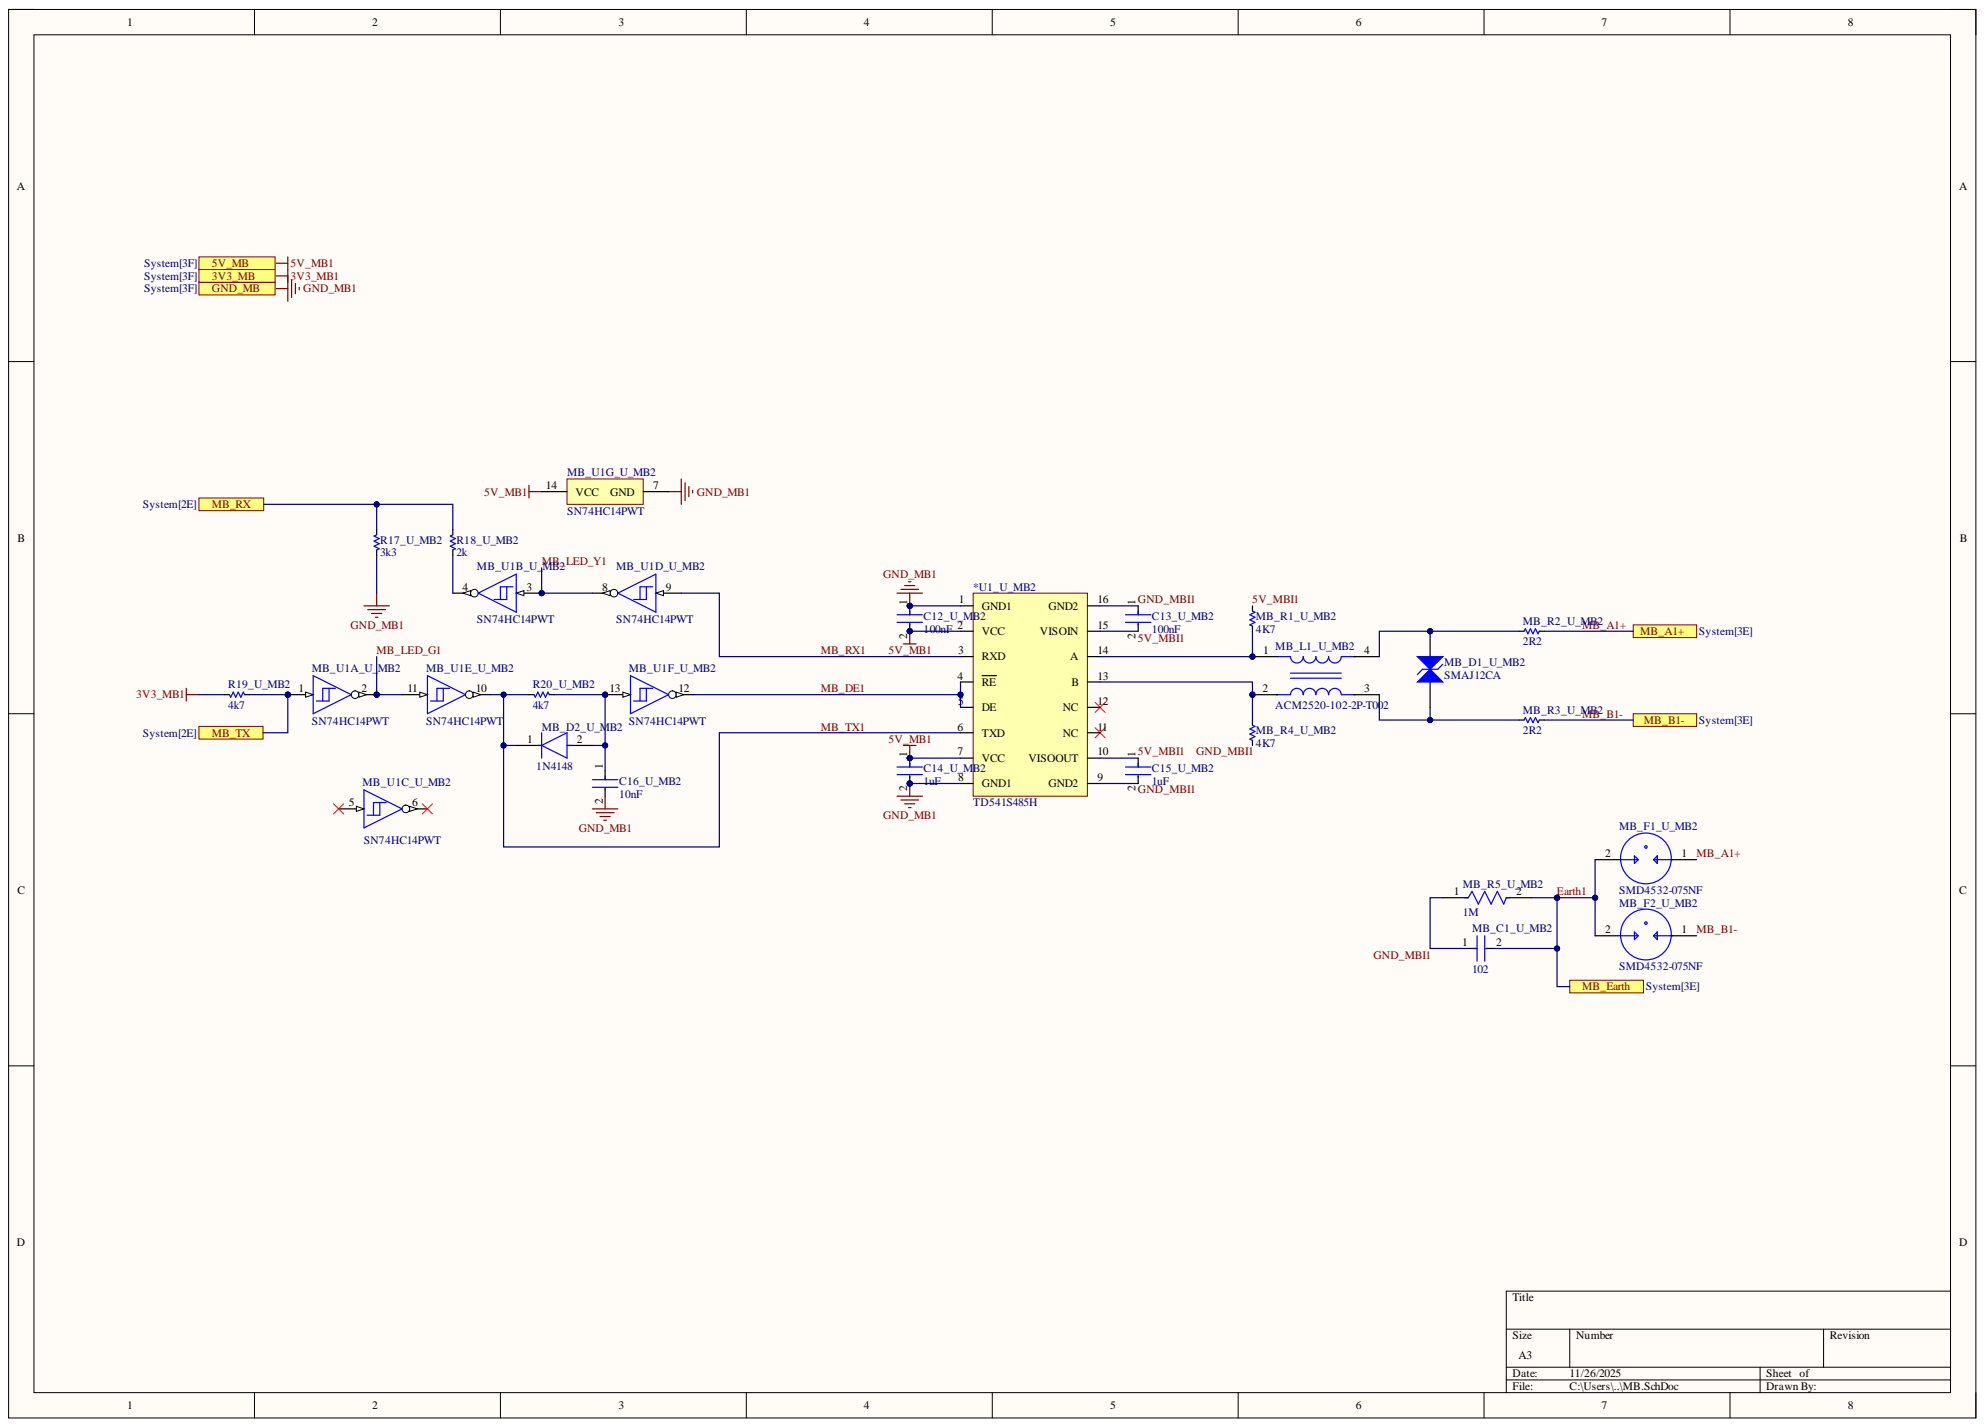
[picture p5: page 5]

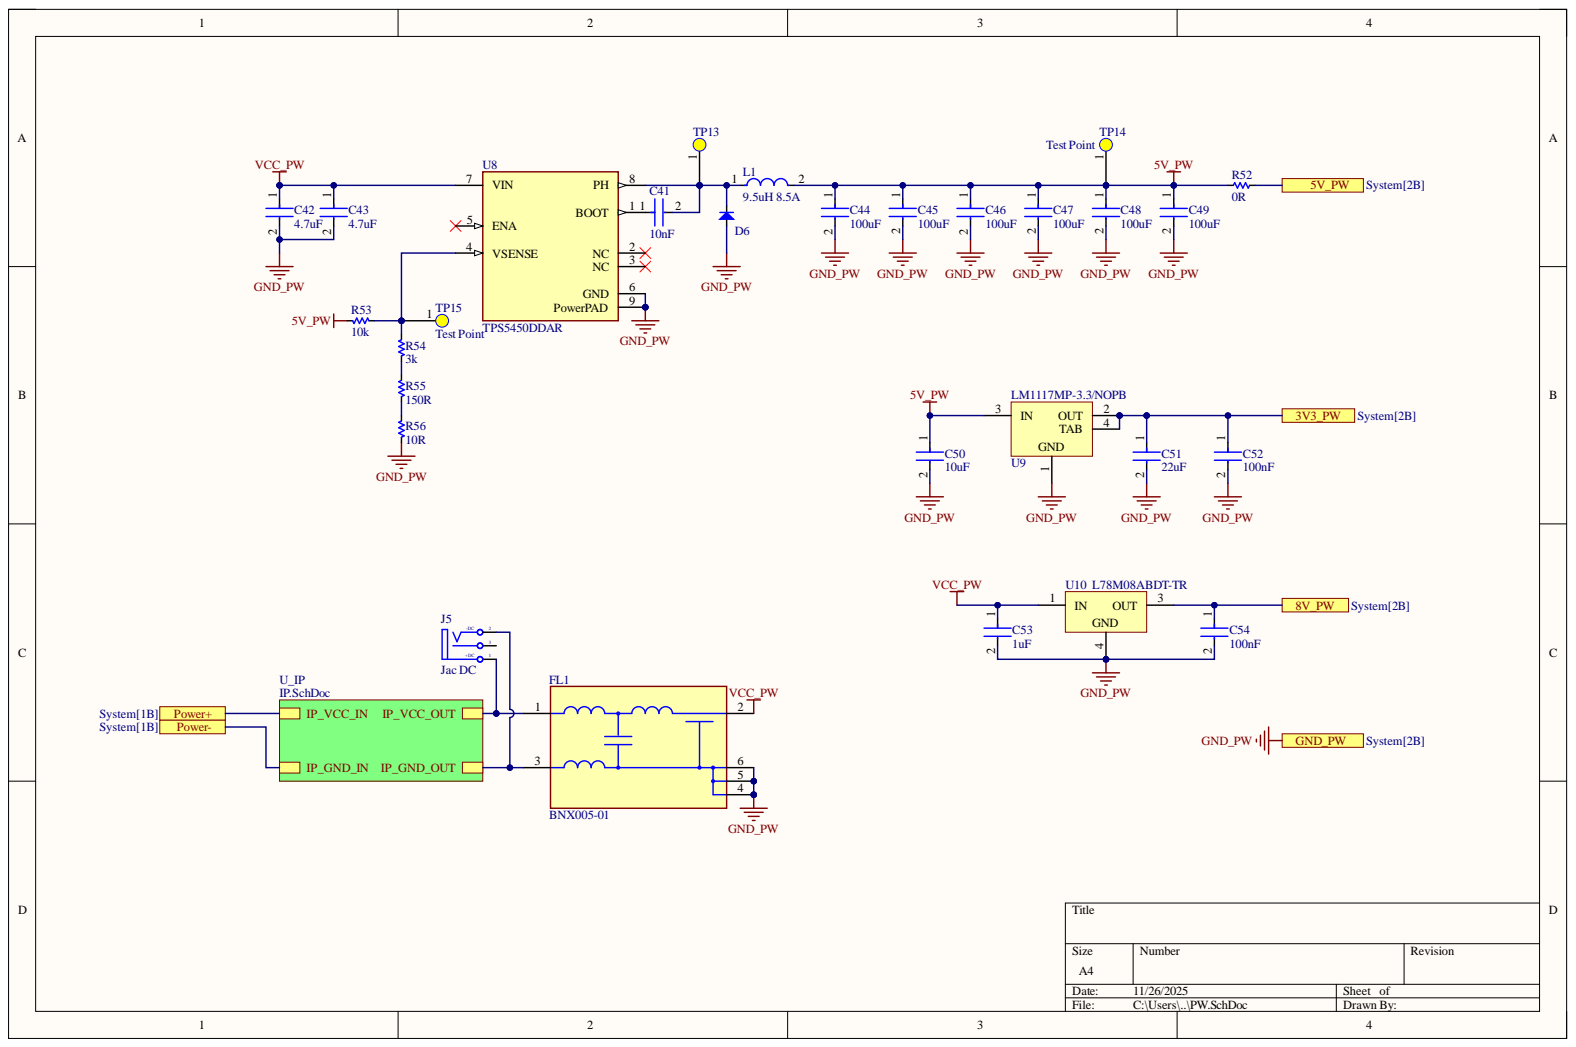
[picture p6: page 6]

Size A4 | Number | Revision

Date: 11/26/2025 | Sheet of
File: C:\Users\..\PW.SchDoc | Drawn By:

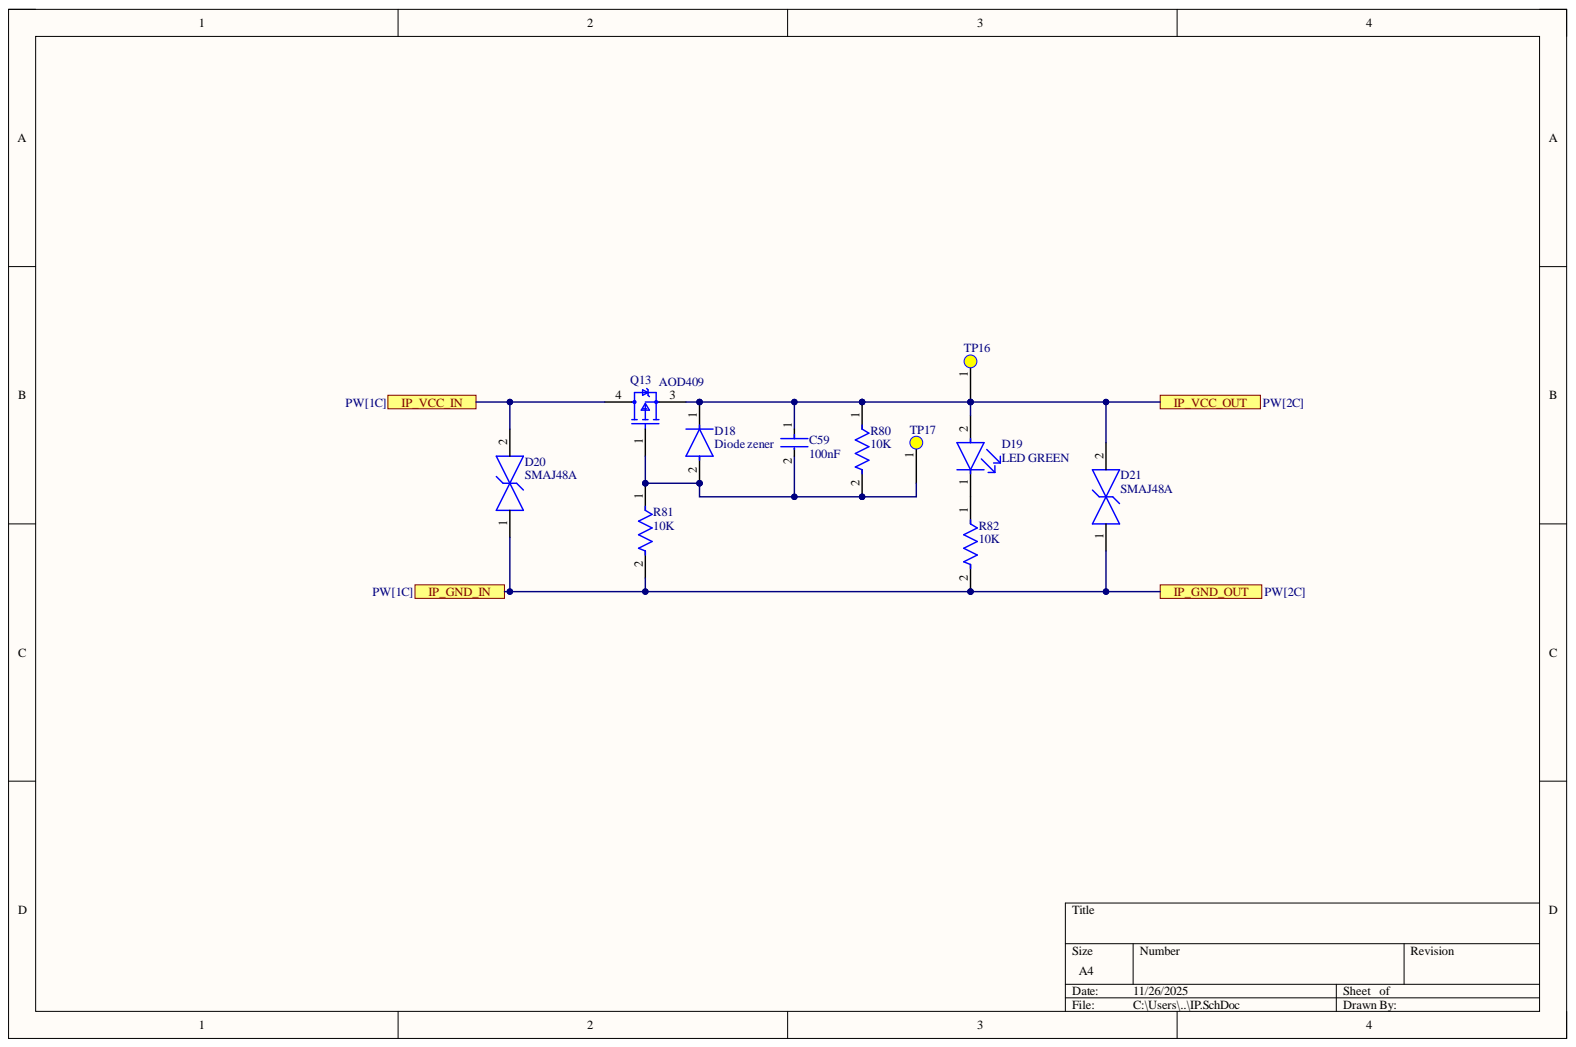
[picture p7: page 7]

Siz e A4 | Numb e r | R evisio n

Da te : 11/26/20 2 5 | She et of
File : C:\Use rs\. .\I P. S c hD o c | Dr awn B y :

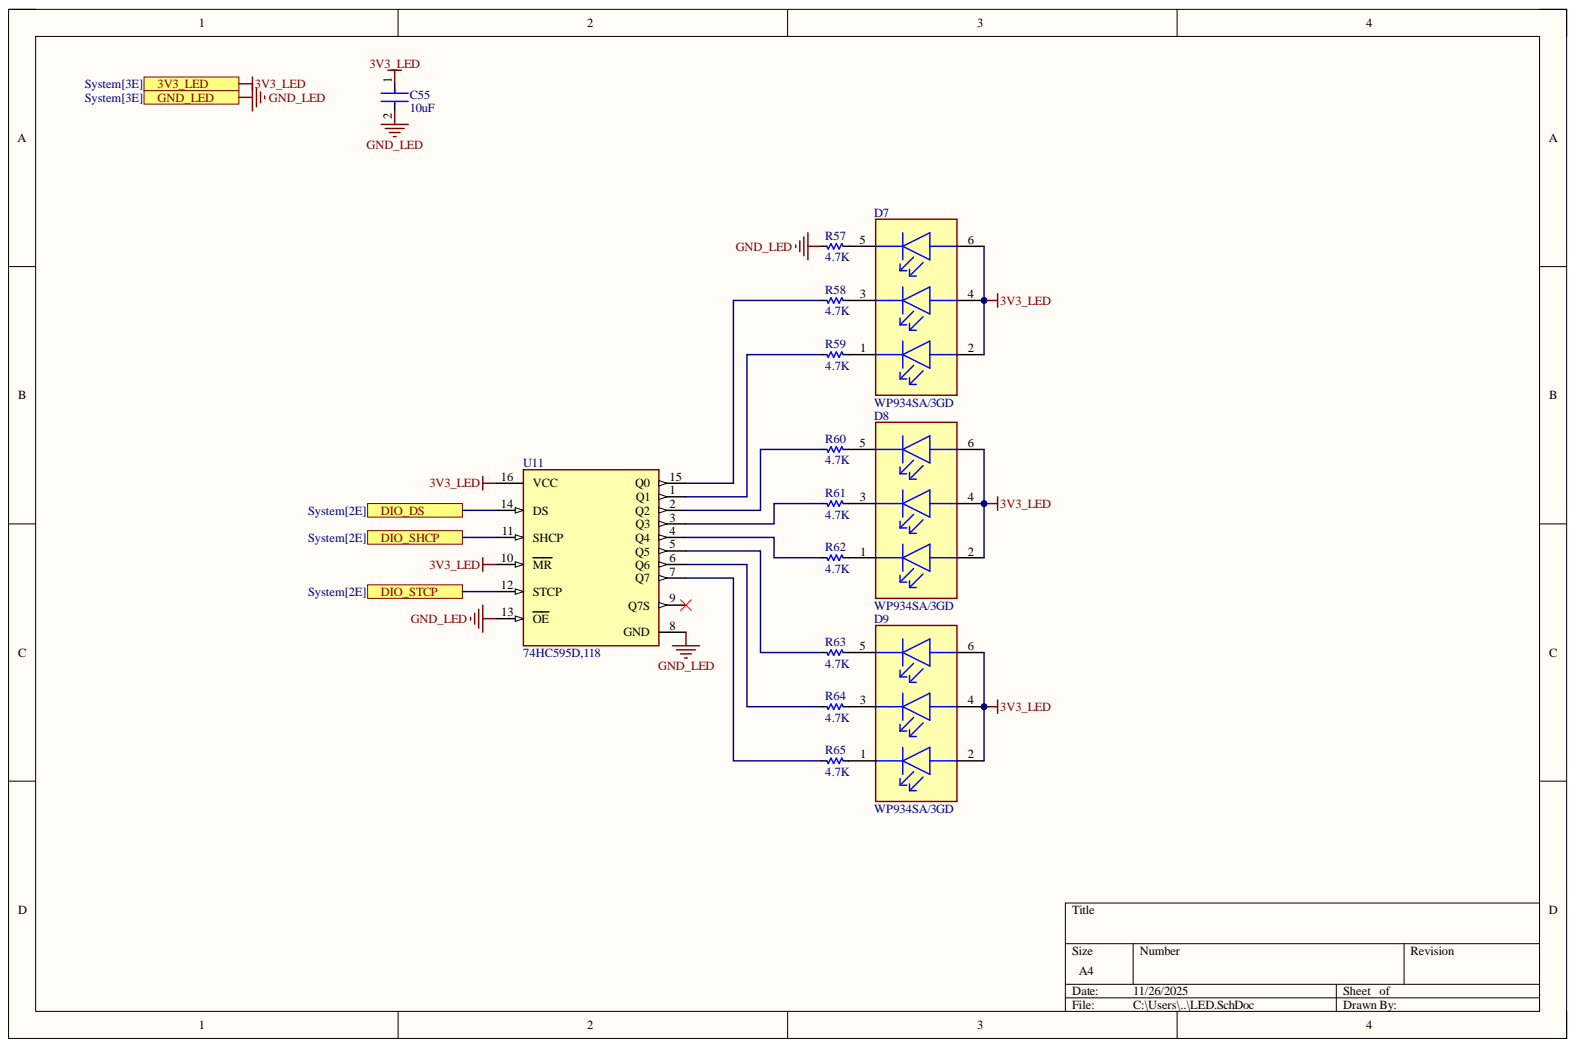
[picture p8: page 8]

Size A4 | Number | Revision

Date: 11/26/2025 | Sheet of
File: C:\Users\..\LED.SchDoc | Drawn By:

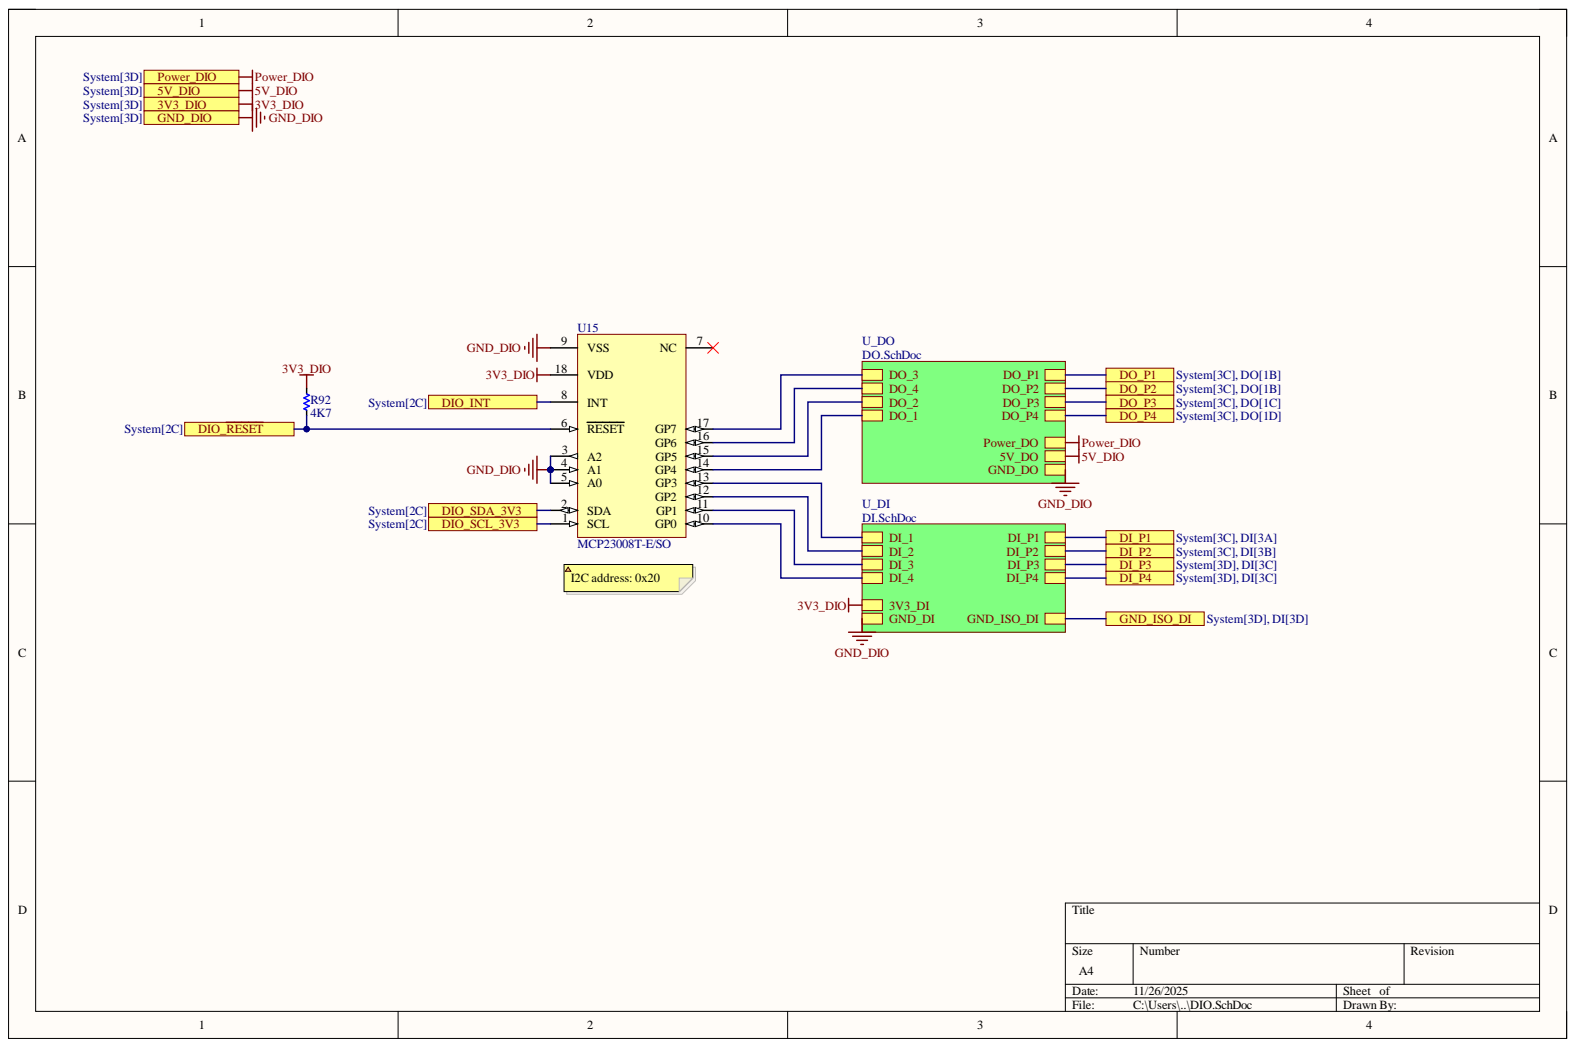
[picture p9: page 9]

Size A4 | Number | Revision

Date: 11/26/2025 | Sheet of
File: C:\Users\..\DIO.SchDoc | Drawn By:

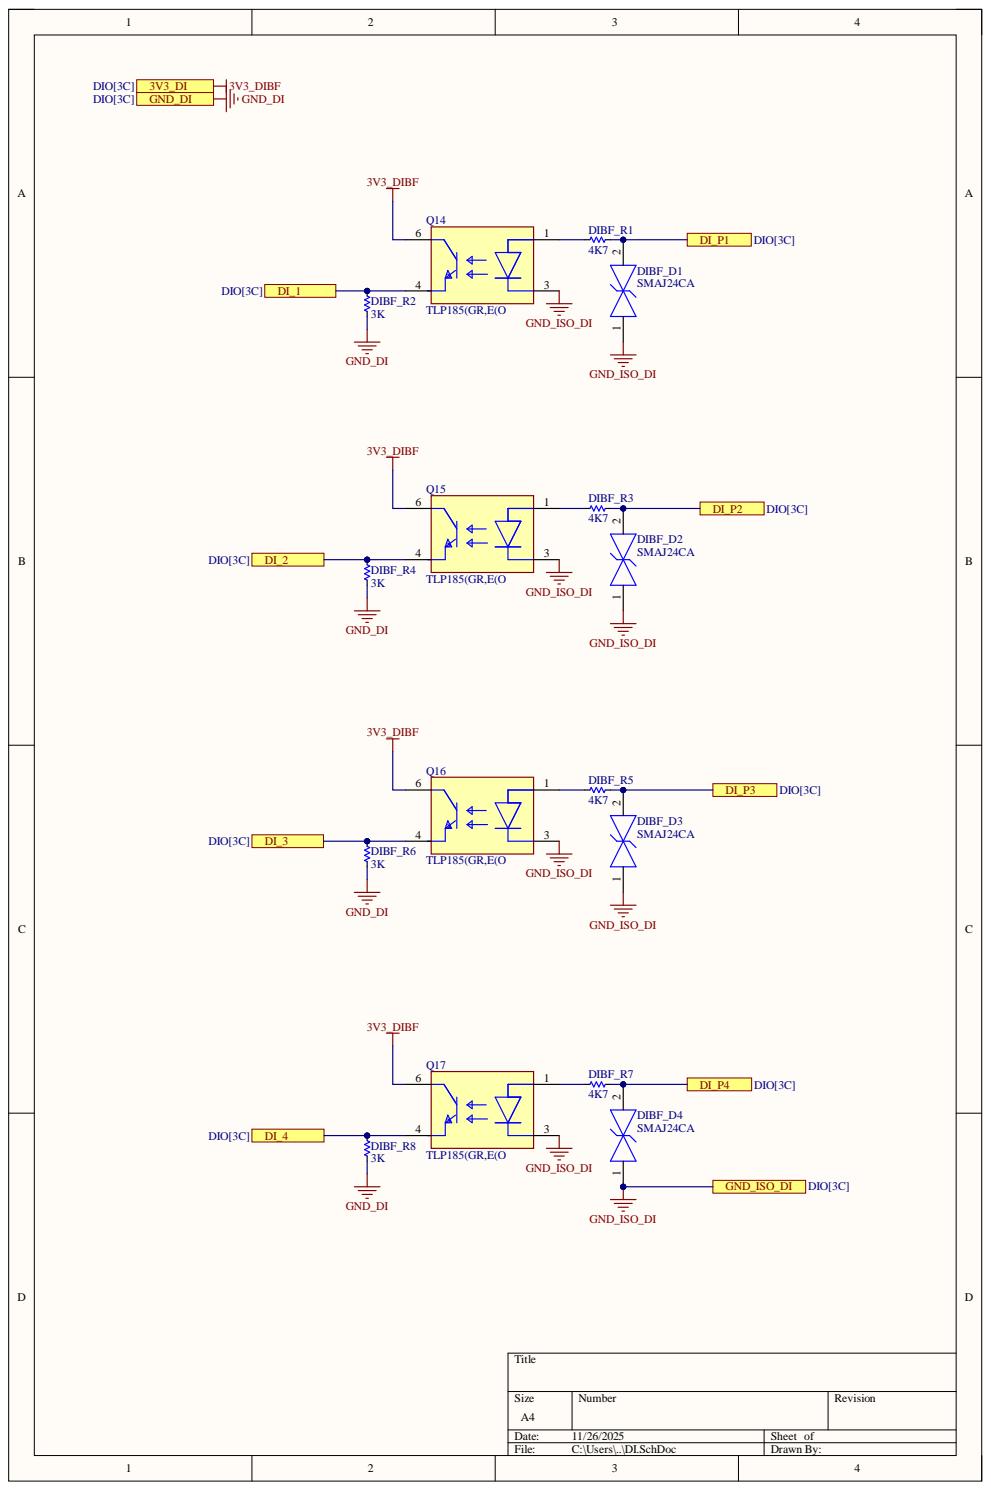
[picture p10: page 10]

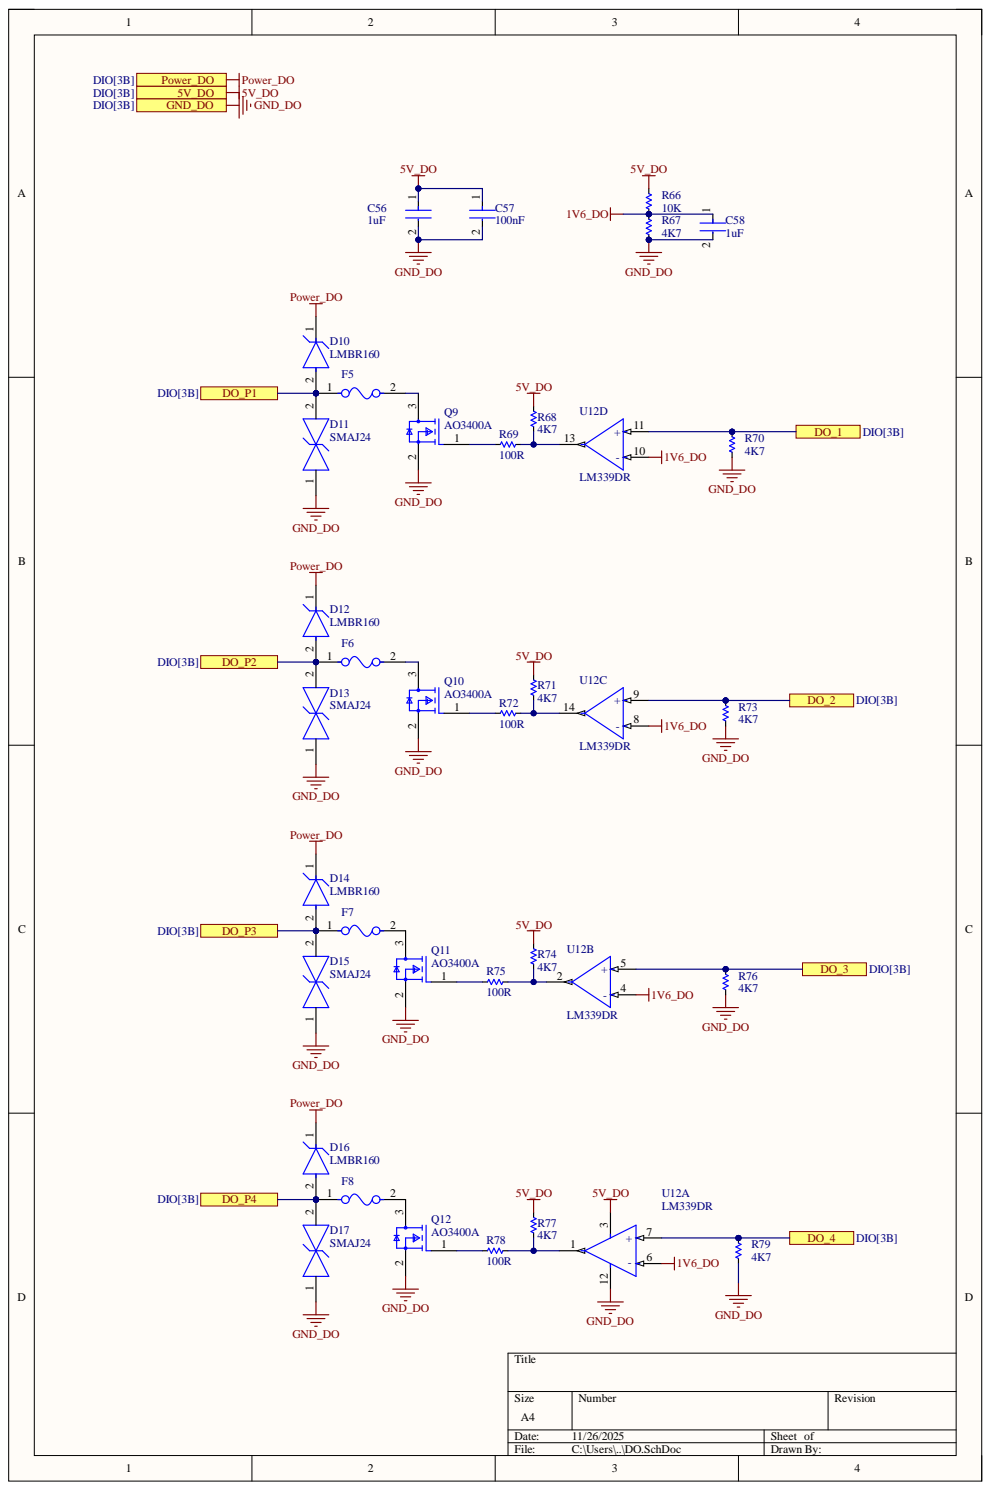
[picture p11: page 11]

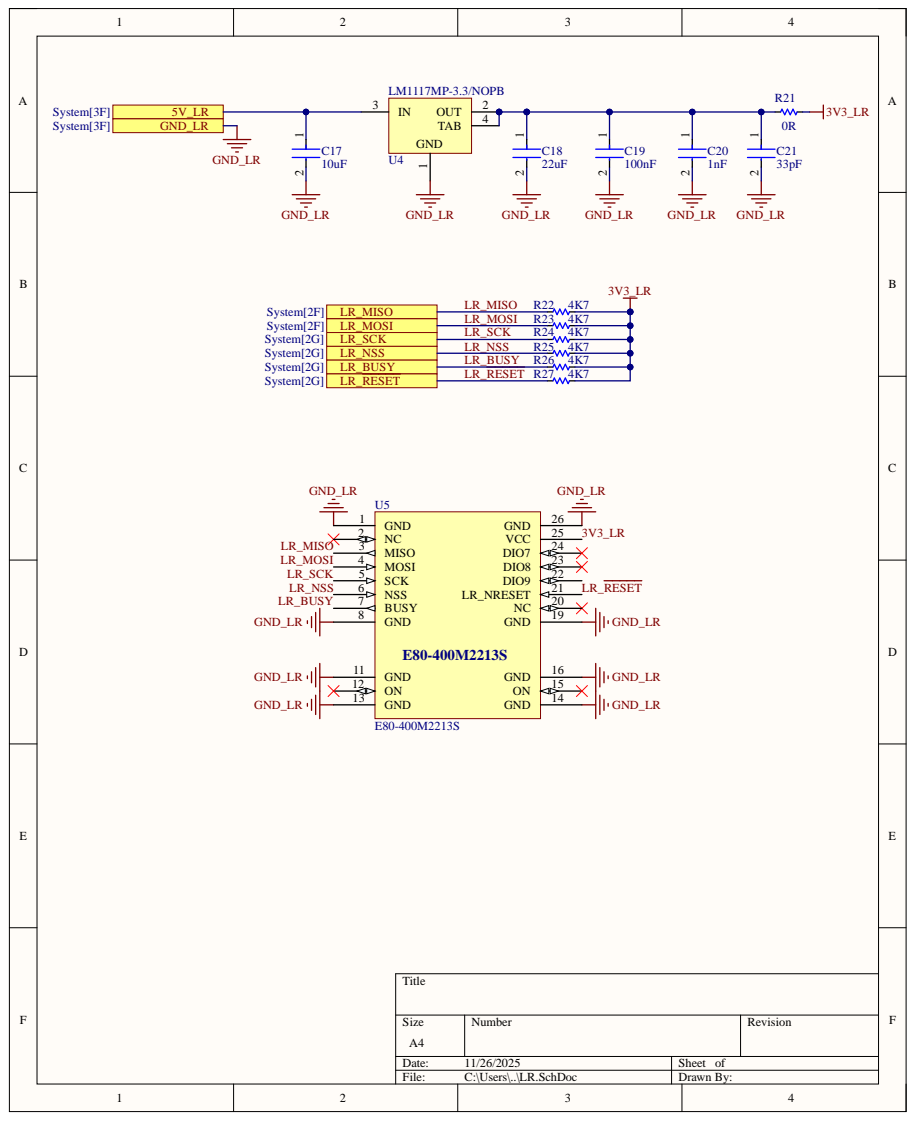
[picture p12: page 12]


External powershould be
able to provide sufficient
current of at least 1.5A.

RST 3

GND 6

MUP-C7801-2 Nano Sim Socket


Adjust the voltage
divider resistor
value to control the
contrast on the
display.




100nF | CAP CER 104 0603, CAP CER 10V X5R 0603, CAP CER 100nF 10V X5R 0603 | C1, C6, C57, C59, C61 | FP-GRM18-0_15-MFG | CMP-2000-05448-2 | 5

1uF | CAP CER 1UF 10V X5R 0603 | C2, C56, C58 | FP-GRM18-0_15-MFG | CMP-2000-05448-2 | 3

10uF | CAP CER 10UF 10V X5R 0603, CAP CER 10V X5R 0603 | C3, C4, C5, C7, C8, C9, C10, C11, C60 | FP-GRM18-0_15-MFG | CMP-2000-05448-2 | 9

100nF | Cap 0805 10% | C12_U_MB1, C12_U_MB2, C13_U_MB1, C13_U_MB2, C52 | FP-GRM21B-0_15-MFG | CMP-2007-03385-2 | 5

1uF | Cap 0805 10% | C14_U_MB1, C14_U_MB2, C15_U_MB1, C15_U_MB2 | FP-GRM21B-0_15-MFG | CMP-2007-03385-2 | 4

10nF | Cap 0805 10% | C16_U_MB1, C16_U_MB2 | FP-GRM21B-0_15-MFG | CMP-2007-03385-2 | 2

10uF | Chip Multilayer Ceramic Capacitors for General Purpose, 0603 | C17, C62, C67 | FP-GRM188-0_1-e0_2_0_55-IPC_A | CMP-2006-02792-2 | 3

22uF | Chip Multilayer Ceramic Capacitors for General Purpose, 0603 | C18, C63 | FP-GRM188-0_1-e0_2_0_55-IPC_A | CMP-2006-02792-2 | 2

100nF | Chip Multilayer Ceramic Capacitors for General Purpose, 0603 | C19, C64, C68, C69 | FP-GRM188-0_1-e0_2_0_55-IPC_A | CMP-2006-02792-2 | 4

1nF | Chip Multilayer Ceramic Capacitors for General Purpose, 0603 | C20, C65 | FP-GRM188-0_1-e0_2_0_55-IPC_A | CMP-2006-02792-2 | 2

33pF | Chip Multilayer Ceramic Capacitors for General Purpose, 0603 | C21, C66 | FP-GRM188-0_1-e0_2_0_55-IPC_A | CMP-2006-02792-2 | 2

1nF | CAP CER 10V X5R 0603 | C22 | FP-GRM18-0_15-MFG | CMP-2000-05448-2 | 1

22pF | Chip Multilayer Ceramic Capacitors for General Purpose, 0603, 10uF, X5R, 15%, 20%, 6.3V | C23, C24 | FP-GRM188-0_1-e0_2_0_55-IPC_C | CMP-2006-02792-2 | 2

100uF | SMD 1210 100UF 107K 3225 25V 20% X5R | C25, C26, C27, C28, C29, C44, C45, C46, C47, C48, C49 | FP-C1210C107M9PACTU-IPC_A | CMP-2000-06018-2 | [NoParam], https://cungcaplin 11 hkien.vn/tu-gom-smd-1210-100uf-107k-3225-25v-20-x5r

100nF | Chip Multilayer Ceramic Capacitors for General Purpose, 0603, 10uF, X5R, 15%, 20%, 6.3V | C30, C40 | FP-GRM188-0_1-e0_2_0_55-IPC_C | CMP-2006-02792-2 | 2

1nF | Chip Multilayer Ceramic Capacitors for General Purpose, 0603, 10uF, X5R, 15%, 20%, 6.3V | C31 | FP-GRM188-0_1-e0_2_0_55-IPC_C | CMP-2006-02792-2 | 1

33pF | Chip Multilayer Ceramic Capacitors for General Purpose, 0603, 10uF, X5R, 15%, 20%, 6.3V | C32, C36, C37, C38, C39 | FP-GRM188-0_1-e0_2_0_55-IPC_C | CMP-2006-02792-2 | 5

10pF | Chip Multilayer Ceramic Capacitors for General Purpose, 0603, 10uF, X5R, 15%, 20%, 6.3V | C33 | FP-GRM188-0_1-e0_2_0_55-IPC_C | CMP-2006-02792-2 | 1

3.9pF | Chip Multilayer Ceramic Capacitors for General Purpose, 0603, 10uF, X5R, 15%, 20%, 6.3V | C34 | FP-GRM188-0_1-e0_2_0_55-IPC_C | CMP-2006-02792-2 | 1

1.8pF | Chip Multilayer Ceramic Capacitors for General Purpose, 0603, 10uF, X5R, 15%, 20%, 6.3V | C35 | FP-GRM188-0_1-e0_2_0_55-IPC_C | CMP-2006-02792-2 | 1

10nF | 0805 10NF 50V | C41 | FP-GRM21B-0_1-IPC_A | CMP-2007-03453-2 | 1
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

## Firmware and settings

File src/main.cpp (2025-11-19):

#include "../src/apps/atApp_CP.h"
#include "../src/apps/atApp_BT.h"
#include "../src/apps/atApp_AI.h"
// #include "../src/apps/atApp_WD.h"
#include "../src/apps/atApp_AP.h"
#include "../src/apps/atApp_DI.h"
#include "../src/apps/atApp_DO.h"
#include "../src/apps/atApp_LED.h"
#include "../src/apps/atApp_LCD.h"
#include "../src/apps/atApp_MB1.h"
#include "../src/apps/atApp_MB2.h"
#include "../src/apps/atApp_Sensor.h"
#include "../src/apps/atApp_RTC_v2.h"
#include "../src/apps/atApp_FTP.h"
#include "../src/apps/atApp_Logger.h"
#include "../src/apps/atApp_ParamSync.h"
// #include "../src/apps/atApp_TestSD.h"
// #include "../src/apps/atApp_TestLCD.h"
// #include "../src/apps/atApp_MQTT_PUB.h"
// #include "../src/apps/atApp_MQTT_SUB.h"
// #include "../src/apps/atApp_RTC.h"
// #include "../src/apps/atApp_TestFTP.h"
// #include "../src/apps/atApp_TestI2CScan.h"
// #include "../src/obj/atObj_Param.h"
// #include "../src/obj/atObj_Data.h"

void setup()
{
  // Reset MCP23008
  pinMode(RESET_PIN, OUTPUT);
  digitalWrite(RESET_PIN, LOW);
  vTaskDelay(10 / portTICK_PERIOD_MS);
  digitalWrite(RESET_PIN, HIGH);
  vTaskDelay(10 / portTICK_PERIOD_MS);

  Serial.begin(115200);
  vTaskDelay(3000 / portTICK_PERIOD_MS);
  // deinit the task watchdog to avoid reset at the beginning
  // esp_task_wdt_delete(NULL);

  // Uncomment to put the app in debug mode
  // atApp_MQTT_PUB.Debug();
  // atApp_MQTT_SUB.Debug();
  // atApp_FTP.Debug();
  // atApp_AI.Debug();
  // atApp_AP.Debug();
  // atApp_BT.Debug();
  // atApp_CP.Debug();
  // atApp_LCD.Debug();
  // atApp_WD.Debug();
  // atApp_LED.Debug();
  // atApp_MB1.Debug();
  // atApp_MB2.Debug();
  // atApp_RTC.Debug();
  // atApp_RTC_v2.Debug();
  // atApp_Sensor.Debug();
  // atApp_Logger.Debug();
  // atApp_ParamSync.Debug();
  // atApp_DI.Debug();
  // atApp_DO.Debug();
  // atApp_GPS.Debug();
  // atApp_TestSD.Debug();
  // atApp_TestFTP.Debug();
  // atApp_TestLCD.Debug();
  // atApp_TestI2CScan.Debug();

  // Uncomment to put the service in debug mode
  

  // --------------------------------------------Tasks table--------------------------------------------//
  // ---------------------------------------------------------------------------------------------------//
  // || Creation  ||  Task function ||  PC name ||  Heap size ||  Parameter ||  Priority  ||  Task handle ||  CoreID  ||
  
  Serial.println("=== Creating FreeRTOS Tasks ===");
  Serial.printf("[MEMORY] Initial Free Heap: %u bytes\n", esp_get_free_heap_size());
  Serial.printf("[MEMORY] Initial Free PSRAM: %u bytes\n", heap_caps_get_free_size(MALLOC_CAP_SPIRAM));
  Serial.printf("[MEMORY] Largest free block: %u bytes\n", heap_caps_get_largest_free_block(MALLOC_CAP_8BIT));
  
  // xTaskCreatePinnedToCore(atApp_WD_Task_Func, "atApp_WD_Application", 2048, NULL, 2, &Task_atApp_WD, 1);

  BaseType_t result = xTaskCreatePinnedToCore(atApp_ParamSync_Task_Func, "atApp_ParamSync_Application", 10000, NULL, 1, &Task_atApp_ParamSync, 1);
  Serial.printf("[TASK] ParamSync Application: %s (Handle: %p)\n", result == pdPASS ? "✅ SUCCESS" : "❌ FAILED", Task_atApp_ParamSync);
  // Wait for ParamSync to complete SD->Param loading
  Serial.println("[MAIN] Waiting for ParamSync to complete...");
  while (atObject_Data.sd_to_param_request)
  {
    vTaskDelay(pdMS_TO_TICKS(100)); // Check every 100ms
  }
  Serial.println("[MAIN] ✅ ParamSync completed, continuing initialization...");
  
  result = xTaskCreatePinnedToCore(atApp_CP_Task_Func, "atApp_CP_Application", 2048, NULL, 1, &Task_atApp_CP, 1);
  Serial.printf("[TASK] CP Application: %s (Handle: %p)\n", result == pdPASS ? "✅ SUCCESS" : "❌ FAILED", Task_atApp_CP);
  
  result = xTaskCreatePinnedToCore(atApp_RTC_v2_Task_Func, "atApp_RTC_v2_Application", 4096, NULL, 1, &Task_atApp_RTC_v2, 1);
  Serial.printf("[TASK] RTC_v2 Application: %s (Handle: %p)\n", result == pdPASS ? "✅ SUCCESS" : "❌ FAILED", Task_atApp_RTC_v2);
  
  result = xTaskCreatePinnedToCore(atApp_AI_Task_Func, "atApp_AI_Application", 2048, NULL, 1, &Task_atApp_AI, 1);
  Serial.printf("[TASK] AI Application: %s (Handle: %p)\n", result == pdPASS ? "✅ SUCCESS" : "❌ FAILED", Task_atApp_AI);
  
  result = xTaskCreatePinnedToCore(atApp_LCD_Task_Func, "atApp_LCD_Application", 4096, NULL, 1, &Task_atApp_LCD, 1);
  Serial.printf("[TASK] LCD Application: %s (Handle: %p)\n", result == pdPASS ? "✅ SUCCESS" : "❌ FAILED", Task_atApp_LCD);
  
  result = xTaskCreatePinnedToCore(atApp_MB1_Task_Func, "atApp_MB1_Application", 4096, NULL, 1, &Task_atApp_MB1, 1);
  Serial.printf("[TASK] MB1 Application: %s (Handle: %p)\n", result == pdPASS ? "✅ SUCCESS" : "❌ FAILED", Task_atApp_MB1);
  
  result = xTaskCreatePinnedToCore(atApp_MB2_Task_Func, "atApp_MB2_Application", 4096, NULL, 1, &Task_atApp_MB2, 1);
  Serial.printf("[TASK] MB2 Application: %s (Handle: %p)\n", result == pdPASS ? "✅ SUCCESS" : "❌ FAILED", Task_atApp_MB2);
  
  result = xTaskCreatePinnedToCore(atApp_Sensor_Task_Func, "atApp_Sensor_Application", 5000, NULL, 1, &Task_atApp_Sensor, 1);
  Serial.printf("[TASK] Sensor Application: %s (Handle: %p)\n", result == pdPASS ? "✅ SUCCESS" : "❌ FAILED", Task_atApp_Sensor);
  
  result = xTaskCreatePinnedToCore(atApp_DI_Task_Func, "atApp_DI_Application", 4096, NULL, 1, &Task_atApp_DI, 1);
  Serial.printf("[TASK] DI Application: %s (Handle: %p)\n", result == pdPASS ? "✅ SUCCESS" : "❌ FAILED", Task_atApp_DI);
  
  result = xTaskCreatePinnedToCore(atApp_DO_Task_Func, "atApp_DO_Application", 4096, NULL, 1, &Task_atApp_DO, 1);
  Serial.printf("[TASK] DO Application: %s (Handle: %p)\n", result == pdPASS ? "✅ SUCCESS" : "❌ FAILED", Task_atApp_DO);
  
  result = xTaskCreatePinnedToCore(atApp_LED_Task_Func, "atApp_LED_Application", 2048, NULL, 1, &Task_atApp_LED, 1);
  Serial.printf("[TASK] LED Application: %s (Handle: %p)\n", result == pdPASS ? "✅ SUCCESS" : "❌ FAILED", Task_atApp_LED);
  
  result = xTaskCreatePinnedToCore(atApp_BT_Task_Func, "atApp_BT_Application", 4096, NULL, 1, &Task_atApp_BT, 1);
  Serial.printf("[TASK] BT Application: %s (Handle: %p)\n", result == pdPASS ? "✅ SUCCESS" : "❌ FAILED", Task_atApp_BT);

  result = xTaskCreatePinnedToCore(atApp_Logger_Task_Func, "atApp_Logger_Application", 30000, NULL, 3, &Task_atApp_Logger, 0);
  Serial.printf("[TASK] Logger Application: %s (Handle: %p)\n", result == pdPASS ? "✅ SUCCESS" : "❌ FAILED", Task_atApp_Logger);
  
  result = xTaskCreatePinnedToCore(atApp_FTP_Task_Func, "atApp_FTP_Application", 40960, NULL, 1, &Task_atApp_FTP, 0);
  Serial.printf("[TASK] FTP Application: %s (Handle: %p)\n", result == pdPASS ? "✅ SUCCESS" : "❌ FAILED", Task_atApp_FTP);
  
  // Check memory before creating AP task
  Serial.printf("[MEMORY] Free Heap before AP task: %u bytes\n", esp_get_free_heap_size());
  Serial.printf("[MEMORY] Free PSRAM before AP task: %u bytes\n", heap_caps_get_free_size(MALLOC_CAP_SPIRAM));
  Serial.printf("[MEMORY] Largest free block: %u bytes\n", heap_caps_get_largest_free_block(MALLOC_CAP_8BIT));
  
  result = xTaskCreatePinnedToCore(atApp_AP_Task_Func, "atApp_AP_Application", 81920, NULL, 4, &Task_atApp_AP, 0);
  Serial.printf("[TASK] AP Application: %s (Handle: %p)\n", result == pdPASS ? "✅ SUCCESS" : "❌ FAILED", Task_atApp_AP);
  
  // Detailed error analysis
  Serial.printf("[DEBUG] AP Application Creation Result: %d\n", result);
  if (result != pdPASS) {
    Serial.println("[ERROR] AP Task Creation Failed!");
    Serial.printf("[ERROR] Required stack: 81920 bytes\n");
    Serial.printf("[ERROR] Available heap: %u bytes\n", esp_get_free_heap_size());
    Serial.printf("[ERROR] Largest block: %u bytes\n", heap_caps_get_largest_free_block(MALLOC_CAP_8BIT));
    
    // Try creating with smaller stack
    Serial.println("[RETRY] Attempting to create AP task with smaller stack...");
    result = xTaskCreatePinnedToCore(atApp_AP_Task_Func, "atApp_AP_Application", 40960, NULL, 4, &Task_atApp_AP, 0);
    Serial.printf("[RETRY] AP Application (40KB): %s (Handle: %p)\n", result == pdPASS ? "✅ SUCCESS" : "❌ FAILED", Task_atApp_AP);
    
    if (result != pdPASS) {
      Serial.println("[RETRY] Attempting to create AP task with even smaller stack...");
      result = xTaskCreatePinnedToCore(atApp_AP_Task_Func, "atApp_AP_Application", 20480, NULL, 4, &Task_atApp_AP, 0);
      Serial.printf("[RETRY] AP Application (20KB): %s (Handle: %p)\n", result == pdPASS ? "✅ SUCCESS" : "❌ FAILED", Task_atApp_AP);
    }
  }

  // xTaskCreatePinnedToCore(atApp_MQTT_PUB_Task_Func, "atApp_MQTT_PUB_Application", 2048, NULL, 1, &Task_atApp_MQTT_PUB, 1);
  // xTaskCreatePinnedToCore(atApp_MQTT_SUB_Task_Func, "atApp_MQTT_SUB_Application", 2048, NULL, 1, &Task_atApp_MQTT_SUB, 1);
  // xTaskCreatePinnedToCore(atApp_GPS_Task_Func, "atApp_GPS_Application", 2048, NULL, 1, &Task_atApp_GPS, 1);
  // xTaskCreatePinnedToCore(atApp_RTC_Task_Func, "atApp_RTC_Application", 10000, NULL, 1, &Task_atApp_RTC, 1);
  // xTaskCreatePinnedToCore(atApp_TestSD_Task_Func, "atApp_TestSD_Application", 10000, NULL, 1, &Task_atApp_TestSD, 1);
  // xTaskCreatePinnedToCore(atApp_TestFTP_Task_Func, "atApp_TestFTP_Application", 10000, NULL, 1, &Task_atApp_TestFTP, 1);
  // xTaskCreatePinnedToCore(atApp_TestLCD_Task_Func, "atApp_TestLCD_Application", 10000, NULL, 1, &Task_atApp_TestLCD, 1);
  // xTaskCreatePinnedToCore(atApp_TestI2CScan_Task_Func, "atApp_TestI2CScan_Application", 2048, NULL, 1, &Task_atApp_TestI2CScan, 1);

  Serial.println("=== Task Creation Summary ===");
  Serial.printf("Total Active Tasks: %d\n", uxTaskGetNumberOfTasks());
  Serial.printf("Free Heap after task creation: %u bytes\n", esp_get_free_heap_size());
  Serial.printf("Free PSRAM after task creation: %u bytes\n", heap_caps_get_free_size(MALLOC_CAP_SPIRAM));
  Serial.printf("Minimum Free Heap: %u bytes\n", esp_get_minimum_free_heap_size());
  Serial.printf("Largest free block: %u bytes\n", heap_caps_get_largest_free_block(MALLOC_CAP_8BIT));
  
  // Memory usage analysis
  size_t total_stack_size = 2048 + 10000 + 2048 + 10000 + 10000 + 10000 + 5000 + 10000 + 10000 + 2048 + 10000 + 30000 + 100000 + 81920;
  Serial.printf("Total allocated stack size: %u bytes (%.1f KB)\n", total_stack_size, total_stack_size / 1024.0);
  
  if (Task_atApp_AP == NULL) {
    Serial.println("⚠️  RECOMMENDATION: Consider reducing AP task stack size or other tasks");
    Serial.println("    - Try AP stack: 40960 (40KB) instead of 81920 (80KB)");
    Serial.println("    - Try FTP stack: 50000 (50KB) instead of 100000 (100KB)");
    Serial.println("    - Or disable some non-critical tasks temporarily");
  }

  //------------------------------------------------------------------------------------------------------//
  // Some tasks will be suspended after initiating
  // vTaskSuspend(Task_atApp_AP);
  // vTaskSuspend(Task_atApp_ABC);
  
  // Suspend AP task by default - it will be resumed when button is held for 5 seconds
  if (Task_atApp_AP != NULL)
  {
    vTaskSuspend(Task_atApp_AP);
    Serial.println("[SUSPEND] ⏸️ AP task suspended by default");
    Serial.printf("[INFO] Active Tasks after suspension: %d\n", uxTaskGetNumberOfTasks());
  }
  else
  {
    Serial.println("[ERROR] ❌ AP task handle is NULL, cannot suspend");
  }
  
  Serial.println("=== System Initialization Complete ===");
  Serial.printf("Final Free Heap: %u bytes\n", esp_get_free_heap_size());
  Serial.printf("Final Free PSRAM: %u bytes\n", heap_caps_get_free_size(MALLOC_CAP_SPIRAM));
  Serial.println("=== Starting Main Application ===");
}
void loop()
{
  vTaskDelete(NULL); // Delete the main loop
}

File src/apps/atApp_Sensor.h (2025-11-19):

#ifndef _Application_atApp_Sensor_
#define _Application_atApp_Sensor_
/* _____PROJECT INCLUDES____________________________________________________ */
#include "App.h"
#include "../src/obj/atObj_Param.h"
#include "../src/obj/atObj_Data.h"
#include "../services/atService_Tool.h"
/* _____DEFINITIONS__________________________________________________________ */

/* _____GLOBAL VARIABLES_____________________________________________________ */
TaskHandle_t Task_atApp_Sensor;
void atApp_Sensor_Task_Func(void *parameter);
///////////////////////////////////////////////Testing part//
/* _____GLOBAL FUNCTION______________________________________________________ */
union
{
	uint32_t u;
	float f;
} converter;
/* _____CLASS DEFINITION_____________________________________________________ */
/**
 * This Application class is the application to manage the
 */
class App_Sensor : public Application
{
public:
	App_Sensor();
	~App_Sensor();
	static float read_raw_rs485(uint8_t slave_rs485_index, uint8_t rs485_channel, uint8_t data_type);
	static float calculate_calib(uint8_t sensor_index);
	static bool calculate_calib_linear_regression(CalibTablePoint *table, bool *enable_list, float raw_value, float *calib_value);
	static void  check_error(uint8_t sensor_index);

protected:
private:
	static void App_Sensor_Pend();
	static void App_Sensor_Start();
	static void App_Sensor_Restart();
	static void App_Sensor_Execute();
	static void App_Sensor_Suspend();
	static void App_Sensor_Resume();
	static void App_Sensor_End();
} atApp_Sensor;
/**
 * This function will be automaticaly calSensor when a object is created by this class
 */
App_Sensor::App_Sensor(/* args */)
{
	_Pend_User = *App_Sensor_Pend;
	_Start_User = *App_Sensor_Start;
	_Restart_User = *App_Sensor_Restart;
	_Execute_User = *App_Sensor_Execute;
	_Suspend_User = *App_Sensor_Suspend;
	_Resume_User = *App_Sensor_Resume;
	_End_User = *App_Sensor_End;

	// change the ID of application
	ID_Application = 1;
	// change the application name
	Name_Application = (char *)"Sensor Application	";
	// change the ID of SNM
}
/**
 * This function will be automaticaly calSensor when the object of class is delete
 */
App_Sensor::~App_Sensor()
{
}
/**
 * Pend to start is the first task of this application it will do prerequisite condition. In the debit mode, task will send information of application to terminal to start the application.
 */
void App_Sensor::App_Sensor_Pend()
{
	// atService_PCF8574.Debug();
}
/**
 * This start function will init some critical function
 */
void App_Sensor::App_Sensor_Start()
{
}
/**
 * Restart function of SNM  app
 */
void App_Sensor::App_Sensor_Restart()
{
}
/**
 * Execute fuction of SNM app
 */
void App_Sensor::App_Sensor_Execute()
{
	// Read all sensor raw value
	for (uint8_t sensor_index = 0; sensor_index < MAX_SENSORS; sensor_index++)
	{
		// check if this sensor is enable
		if (atObject_Param.sensor_enable_list[sensor_index] == true)
		{
			switch (atObject_Param.sensor_protocol_list[sensor_index])
			{
			case PROTOCOL_RS485_CH1:
				// if this sensor is enable and protocol is PROTOCOL_RS485_CH1
				atObject_Data.sensor_raw_value_list[sensor_index] = atApp_Sensor.read_raw_rs485(
					atObject_Param.sensor_rs485_index[RS485_CHANNEL_1][sensor_index],
					RS485_CHANNEL_1,
					atObject_Param.sensor_data_type_list[sensor_index]);
				// Serial.printf("\tRead RS485 CH1 Sensor %d: Raw Value = %.2f\n", sensor_index, atObject_Data.sensor_raw_value_list[sensor_index]);
				break;

			case PROTOCOL_RS485_CH2:
				// if this sensor is enable and protocol is PROTOCOL_RS485_CH2
				// print atObject_Param.sensor_rs485_index[PROTOCOL_RS485_CH2][sensor_index],
				// Serial.printf("\t---> Reading Sensor %d with RS485 Index %d on RS485 Channel 2\n",
				// 			  sensor_index,
				// 			  atObject_Param.sensor_rs485_index[RS485_CHANNEL_2][sensor_index]);
				atObject_Data.sensor_raw_value_list[sensor_index] = atApp_Sensor.read_raw_rs485(
					atObject_Param.sensor_rs485_index[RS485_CHANNEL_2][sensor_index],
					RS485_CHANNEL_2,
					atObject_Param.sensor_data_type_list[sensor_index]);
				// Serial.printf("\tRead RS485 CH2 Sensor %d: Raw Value = %.2f\n", sensor_index, atObject_Data.sensor_raw_value_list[sensor_index]);
				break;

			case PROTOCOL_ADC_4_20mA_CH1:
				// if this sensor is enable and protocol is PROTOCOL_ADC_4_20mA_CH1
				atObject_Data.sensor_raw_value_list[sensor_index] = (float)atObject_Data.ai_current[AI_CHANNEL_1];
				// Serial.printf("\t---> Reading Sensor %d from ADC CH1 with Raw Value = %.2f\n",
				// 			  sensor_index,
				// 			  atObject_Data.ai_current[AI_CHANNEL_1]);
				// Serial.printf("\tRead ADC CH1 Sensor %d: Raw Value = %.2f\n", sensor_index, atObject_Data.sensor_raw_value_list[sensor_index]);
				break;
			case PROTOCOL_ADC_4_20mA_CH2:
				// if this sensor is enable and protocol is PROTOCOL_ADC_4_20mA_CH2
				atObject_Data.sensor_raw_value_list[sensor_index] = (float)atObject_Data.ai_current[AI_CHANNEL_2];
				// Serial.printf("\t---> Reading Sensor %d from ADC CH2 with Raw Value = %.2f\n",
				// 			  sensor_index,
				// 			  atObject_Data.ai_current[AI_CHANNEL_2]);
				// Serial.printf("\tRead ADC CH2 Sensor %d: Raw Value = %.2f\n", sensor_index, atObject_Data.sensor_raw_value_list[sensor_index]);
				break;
			case PROTOCOL_ADC_4_20mA_CH3:
				// if this sensor is enable and protocol is PROTOCOL_ADC_4_20mA_CH3
				atObject_Data.sensor_raw_value_list[sensor_index] = (float)atObject_Data.ai_current[AI_CHANNEL_3];
				// Serial.printf("\t---> Reading Sensor %d from ADC CH3 with Raw Value = %.2f\n",
				// 			  sensor_index,
				// 			  atObject_Data.ai_current[AI_CHANNEL_3]);
				// Serial.printf("\tRead ADC CH3 Sensor %d: Raw Value = %.2f\n", sensor_index, atObject_Data.sensor_raw_value_list[sensor_index]);
				break;
			case PROTOCOL_ADC_4_20mA_CH4:
				// if this sensor is enable and protocol is PROTOCOL_ADC_4_20mA_CH4
				atObject_Data.sensor_raw_value_list[sensor_index] = (float)atObject_Data.ai_current[AI_CHANNEL_4];
				// Serial.printf("\t---> Reading Sensor %d from ADC CH4 with Raw Value = %.2f\n",
				// 			  sensor_index,
				// 			  atObject_Data.ai_current[AI_CHANNEL_4]);
				// Serial.printf("\tRead ADC CH4 Sensor %d: Raw Value = %.2f\n", sensor_index, atObject_Data.sensor_raw_value_list[sensor_index]);
				break;
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

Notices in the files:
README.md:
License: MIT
